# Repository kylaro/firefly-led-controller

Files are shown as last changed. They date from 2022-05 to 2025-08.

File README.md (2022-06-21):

# firefly-led-controller
PCB for the FireFly LED Controller by kylarLEDs

## Hardware
    The sensors on the board are:
        1. Microphone  -> for sound reactive LEDs
        2. Potentiometer  -> for brightness control
        3. Rotary encoder  -> for color/hue control
        4. Rotary encoder button  -> for changing patterns

    The outputs from the board are:
        1. 2 x WS2812B LED output pins 
            a. Each pin has 2 output pads, one on front and one on back
            b. Each pin has a 0.1 inch header port
        2. 2 x USBC 5V power up to 3A

    The input to the boards are:
        1. Pico programming micro usb port (not meant for power)
        2. 1 x USBC 5V power up to 3A

## Notes
Necessary improvements:
  * Support for 4 pin ws2812b strips, and APA102, 4 outputs
  * More testing capability for the microphone, and maybe other components
*     -> maybe bottom of board row of headers that another board with a pi can plug into, or row of pads on bottom
*     -> Or pad groups on the bottom, like this to that type things... every connection could be represented
*     -> ex. MIC GND <-> GND ... ENC_A <-> GP22 ..., anything that contributes functionality :) 
  * 4 LED outputs
  * Header pins offset

Possibile Improvements to make:
    *WIRELESS:
    *Add ESP32 S2 ($2) with PCB antenna, may need a 3.3V regulator unless the 3.3V port can handle it
  * Add a power MOSFET to turn on / off the power to LEDs
  * Have power pads for screw down crimped ring terminals?
  * Have a hole on the board to weave the LED wire through to add mechanical stability to solder connections
  * Support for 12V on board? (5v regulator, 5v dataline, but 12v power)
  * Support for automatically detecting strip length based on current drawn by strip (either "off" current or turning 1 on at a time, need ammeter)
  * Support for battery charging
  * Support for DMX LEDs input/output
  * Add more sensors, like motion sensor for human presence detection. Temperature/accelerometer/humidity/gyro...
  * Add silabs MCU for mesh networking
  * Stop using Pico board, use the RP2040 + pico schematic so we aren't soldering a board onto a board!

Notes:
  * USB C holes should be more exact so it fits better

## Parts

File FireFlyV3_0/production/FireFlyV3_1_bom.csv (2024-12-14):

Designator | Footprint | Quantity | Value | LCSC Part #
AE1 | FILTER-SMD_1206-2P-L3.2-W1.6-L | 1 | RFANT3216120A5T | C127629
C1, C10, C12, C13, C14, C16, C20, C24, C26, C3, C4, C5, C9 | 0402 | 13 | 100n | C1525
C11, C8 | 0402 | 2 | 15pF | C1548
C15, C18, C19 | 0603 | 3 | 10uF | C19702
C2 | 0402 | 1 | 2.2u | C12530
C21, C22 | 0402 | 2 | 1.5pF | C1552
C23, C25 | 0402 | 2 | 10pF | C32949
C6, C7 | 0402 | 2 | 1u | C52923
D1 | 0603 | 1 | LED, Yellow | C72038
D2 | D_SMA | 1 | SS34 | C8678
D3 | 0603 | 1 | LED, RED | C2286
J1, J2 | PinHeader_1x23_P2.54mm_Vertical | 2 | Conn_01x23
L1 | 0402 | 1 | 2.7nH | C98058
L2 | 0402 | 1 | 6.8nH | C77110
MIC1 | LGA-6_L4.7-W3.8-P1.65_LMD4737T | 1 | LMD4737T263-OY1 | C5373239
R1, R11, R13, R5 | 0402 | 4 | 22R | C25092
R10 | 0402 | 1 | 470R | C25117
R15, R16, R2, R9 | 0402 | 4 | 10K | C25744
R17, R6 | 0402 | 2 | 220R | C25091
R3 | 0402 | 1 | 200R | C25087
R4, R7 | 0402 | 2 | 1K | C11702
R8 | 0402 | 1 | 0R | C17168
SW1, SW2, SW3, SW4 | SW_SPST_TL3342 | 4 | BTN | C318884
U2 | SOIC-8_5.275x5.275mm_P1.27mm | 1 | W25Q128JVS | C97521
U3 | QFN-56-1EP_7x7mm_P0.4mm_EP3.2x3.2mm | 1 | RP2040 | C2040
U4 | SOT-223-3_TabPin2 | 1 | AMS1117-3.3 | C6186
U5 | ESP32-C3FH4 | 1 | ESP32-C3FH4 | C2858491
USB1, USB2 | USB-C_SMD-TYPE-C-31-M-12 | 2 | USB-TYPE-C-018 | C2927038
Y1 | Crystal_SMD_3225-4Pin_3.2x2.5mm | 1 | 12MHz, X322512MSB4SI | C9002
Y2 | Crystal_SMD_2520-4Pin_2.5x2.0mm | 1 | 40MHz, X252040MMB4SI | C2885592

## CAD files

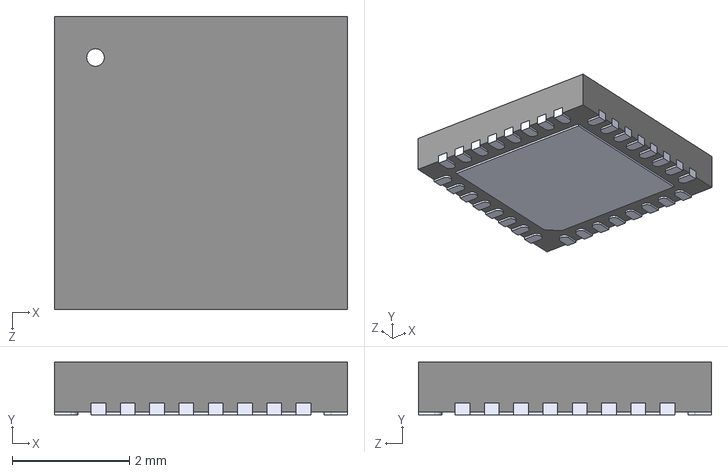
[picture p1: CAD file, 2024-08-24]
FireFlyV3_0/External_Components/models.3d/ESP32-C3FH4.step
5.00 x 0.9 x 5.00 mm

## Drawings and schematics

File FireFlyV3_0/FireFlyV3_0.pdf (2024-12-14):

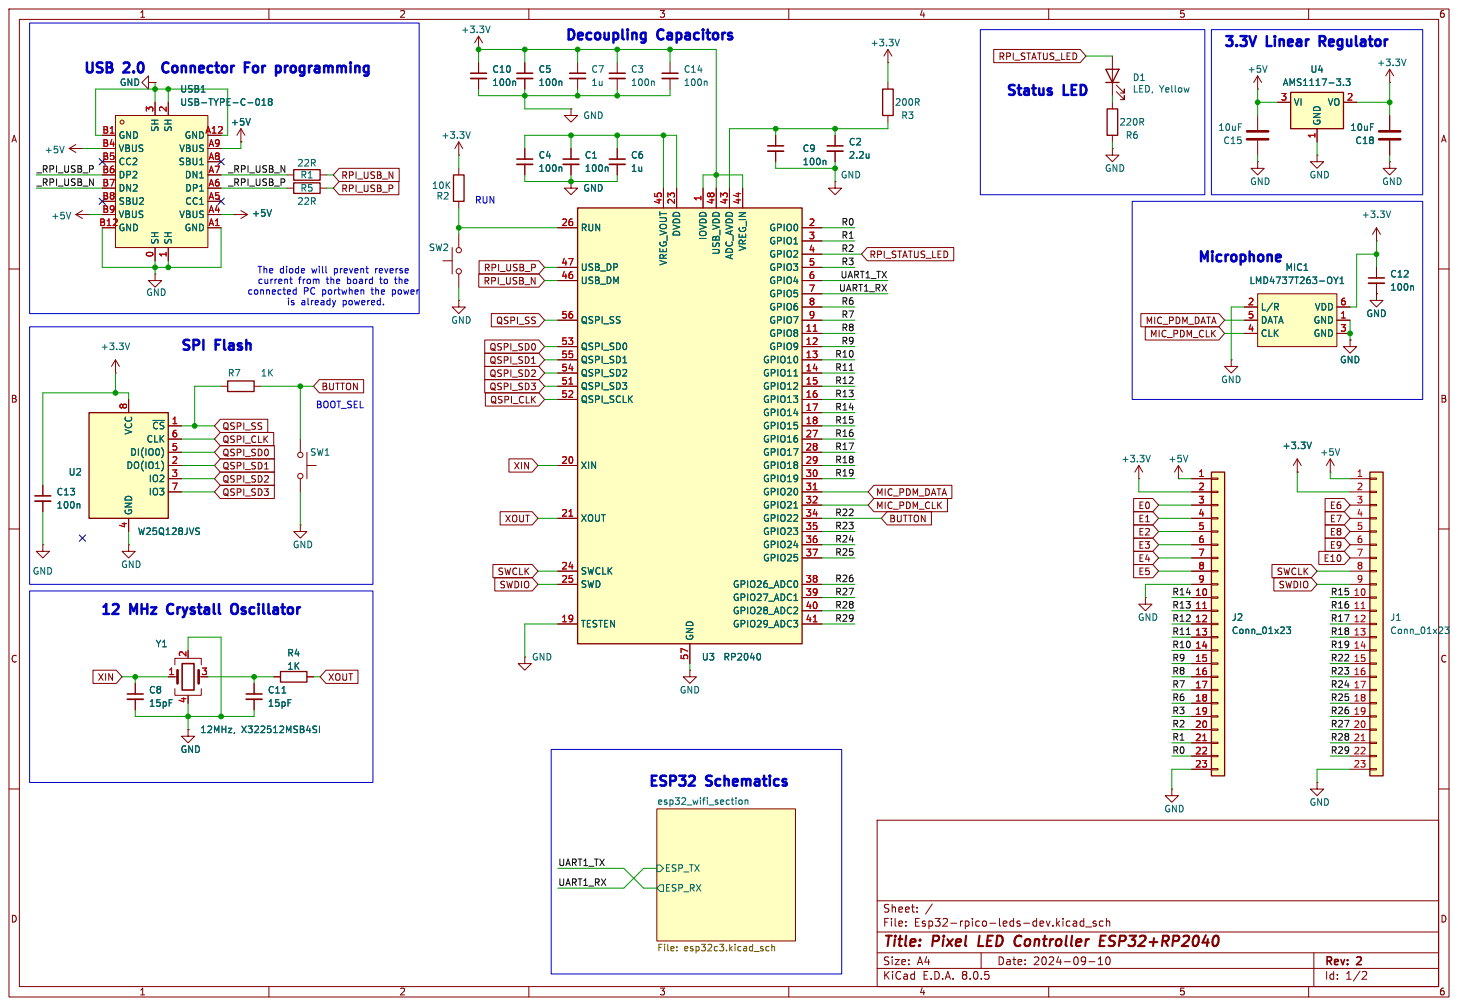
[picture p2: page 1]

3 GND A1 GNDA12 VBUS A4 CC1 A5 DP1 A6 DN1 A7 SBU1 A8 VBUS A9 GND B1 GND B12 VBUS B4 CC2 B5 DP2 B6 DN2 B7 SBU2 B8 VBUS B9 SH

1 GPIO8 11 GPIO9 12 GPIO10 13 GPIO11 14 GPIO12 15 GPIO13 16 GPIO14 17 GPIO15 18 TESTEN 19 GPIO0 2 XIN 20 XOUT 21 DVDD 23 SWCLK 24 SWD 25 RUN 26 GPIO16 27 GPIO17 28 GPIO18 29 GPIO1 3 GPIO19 30 GPIO20 31 GPIO21 32 GPIO22 34 GPIO23 35 GPIO24 36 GPIO25 37 GPIO26_ADC0 38 GPIO27_ADC1 39 GPIO2 4 GPIO28_ADC2 40 GPIO29_ADC3 41 ADC_AVDD 43 VREG_IN 44 VREG_VOUT 45 USB_DM 46 USB_DP 47 USB_VDD 48 GPIO3 5 QSPI_SD3 51 QSPI_SCLK 52 QSPI_SD0 53 QSPI_SD2 54 QSPI_SD1 55 QSPI_SS 56 GND 57 GPIO4 6 GPIO5 7 GPIO6 8 GPIO7 9 U3 RP2040 +5V R3
U3 RP2040 IOVDD

1 GPIO8 11 GPIO9 12 GPIO10 13 GPIO11 14 GPIO12 15 GPIO13 16 GPIO14 17 GPIO15 18 TESTEN 19 GPIO0 2 XIN 20 XOUT 21 DVDD 23 SWCLK 24 SWD 25 RUN 26 GPIO16 27 GPIO17 28 GPIO18 29 GPIO1 3 GPIO19 30 GPIO20 31 GPIO21 32 GPIO22 34 GPIO23 35 GPIO24 36 GPIO25 37 GPIO26_ADC0 38 GPIO27_ADC1 39 GPIO2 4 GPIO28_ADC2 40 GPIO29_ADC3 41 ADC_AVDD 43 VREG_IN 44 VREG_VOUT 45 USB_DM 46 USB_DP 47 USB_VDD 48 GPIO3 5 QSPI_SD3 51 QSPI_SCLK 52 QSPI_SD0 53 QSPI_SD2 54 QSPI_SD1 55 QSPI_SS 56 GND 57 GPIO4 6 GPIO5 7 GPIO6 8 GPIO7 9 +5V

The diode will prevent reverse
current from the board to the

File: Esp32-rpico-leds-dev.kicad_sch Sheet: / ESP_TX
ESP_RX

Id: 1/2 Title: Pixel LED Controller ESP32+RP2040

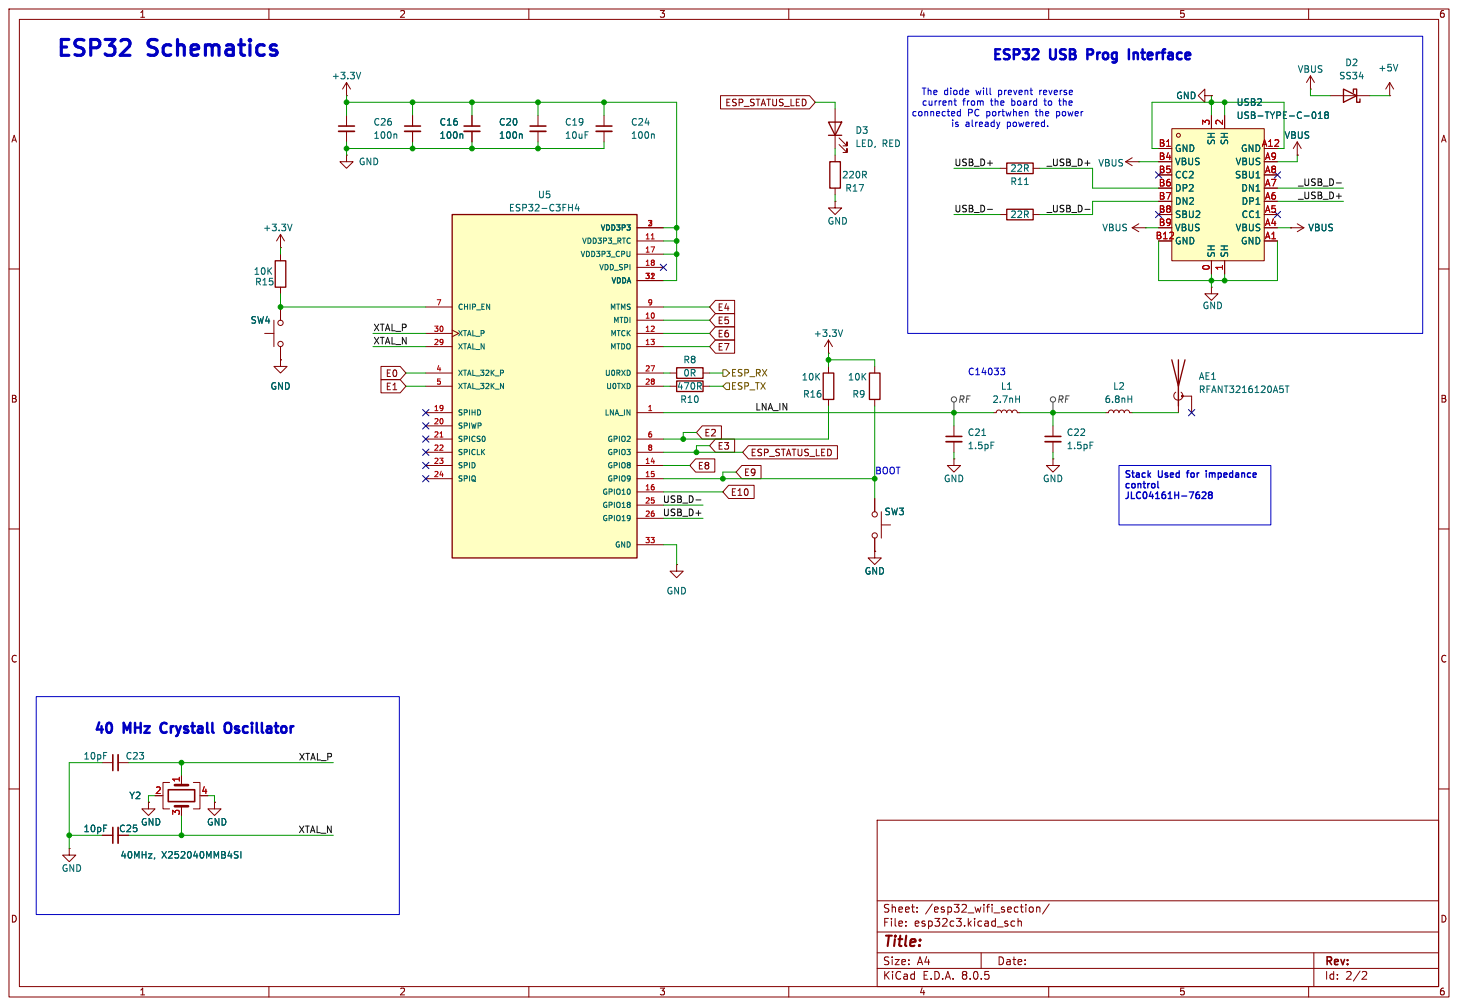
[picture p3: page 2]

The diode will prevent reverse
current from the board to the

1 USB2 USB-TYPE-C-018 VBUS RF RF ESP_TX
ESP_STATUS_LED

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

C14033 BOOT 40 MHz Crystall Oscillator
10K GND

Stack Used for impedance

Id: 2/2 Title: File: esp32c3.kicad_sch Sheet: /esp32_wifi_section/

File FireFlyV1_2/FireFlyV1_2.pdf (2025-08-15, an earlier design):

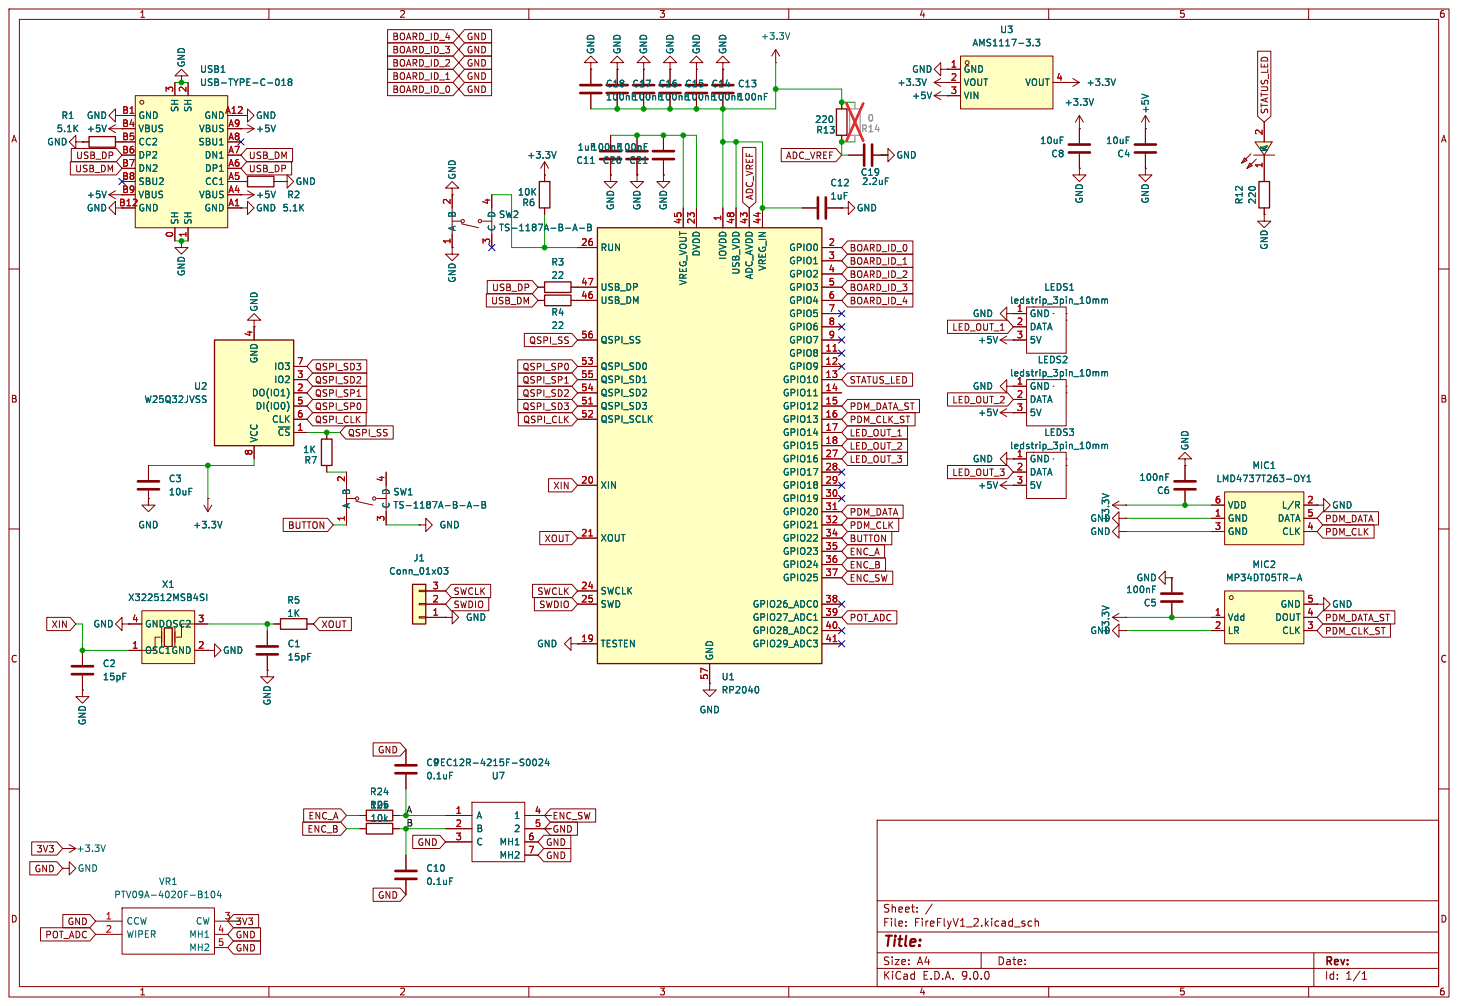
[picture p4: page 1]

1uF GND
+3.3V GND GND+3.3V GND GND

2 GNDA12 VBUS A9 SBU1 A8 DN1 A7 DP1 A6 CC1 A5 VBUS A4 GND A1 SH

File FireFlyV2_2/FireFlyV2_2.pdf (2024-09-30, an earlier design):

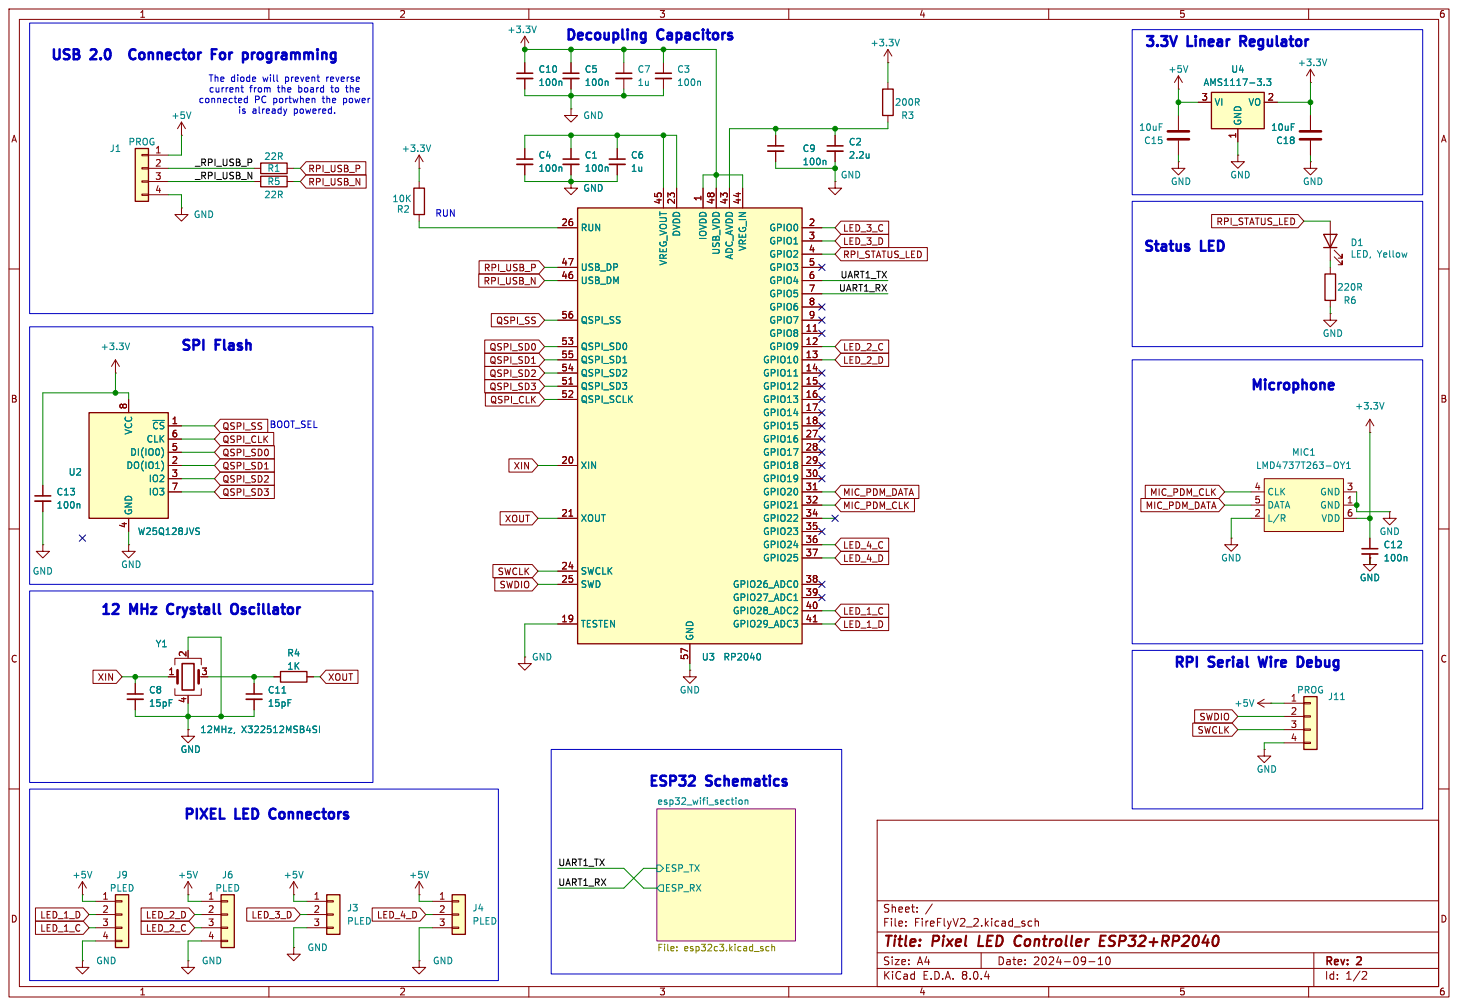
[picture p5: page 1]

+3.3V GND
The diode will prevent reverse
current from the board to the

1 GPIO8 11 GPIO9 12 GPIO10 13 GPIO11 14 GPIO12 15 GPIO13 16 GPIO14 17 GPIO15 18 TESTEN 19 GPIO0 2 XIN 20 XOUT 21 DVDD 23 SWCLK 24 SWD 25 RUN 26 GPIO16 27 GPIO17 28 GPIO18 29 GPIO1 3 GPIO19 30 GPIO20 31 GPIO21 32 GPIO22 34 GPIO23 35 GPIO24 36 GPIO25 37 GPIO26_ADC0 38 GPIO27_ADC1 39 GPIO2 4 GPIO28_ADC2 40 GPIO29_ADC3 41 ADC_AVDD 43 VREG_IN 44 VREG_VOUT 45 USB_DM 46 USB_DP 47 USB_VDD 48 GPIO3 5 QSPI_SD3 51 QSPI_SCLK 52 QSPI_SD0 53 QSPI_SD2 54 QSPI_SD1 55 QSPI_SS 56 GND 57 GPIO4 6 GPIO5 7 GPIO6 8 GPIO7 9 U3 RP2040

1 GPIO8 11 GPIO9 12 GPIO10 13 GPIO11 14 GPIO12 15 GPIO13 16 GPIO14 17 GPIO15 18 TESTEN 19 GPIO0 2 XIN 20 XOUT 21 DVDD 23 SWCLK 24 SWD 25 RUN 26 GPIO16 27 GPIO17 28 GPIO18 29 GPIO1 3 GPIO19 30 GPIO20 31 GPIO21 32 GPIO22 34 GPIO23 35 GPIO24 36 GPIO25 37 GPIO26_ADC0 38 GPIO27_ADC1 39 GPIO2 4 GPIO28_ADC2 40 GPIO29_ADC3 41 ADC_AVDD 43 VREG_IN 44 VREG_VOUT 45 USB_DM 46 USB_DP 47 USB_VDD 48 GPIO3 5 QSPI_SD3 51 QSPI_SCLK 52 QSPI_SD0 53 QSPI_SD2 54 QSPI_SD1 55 QSPI_SS 56 GND 57 GPIO4 6 GPIO5 7 GPIO6 8 GPIO7 9 GND

RPI Serial Wire Debug

Id: 1/2 Title: Pixel LED Controller ESP32+RP2040

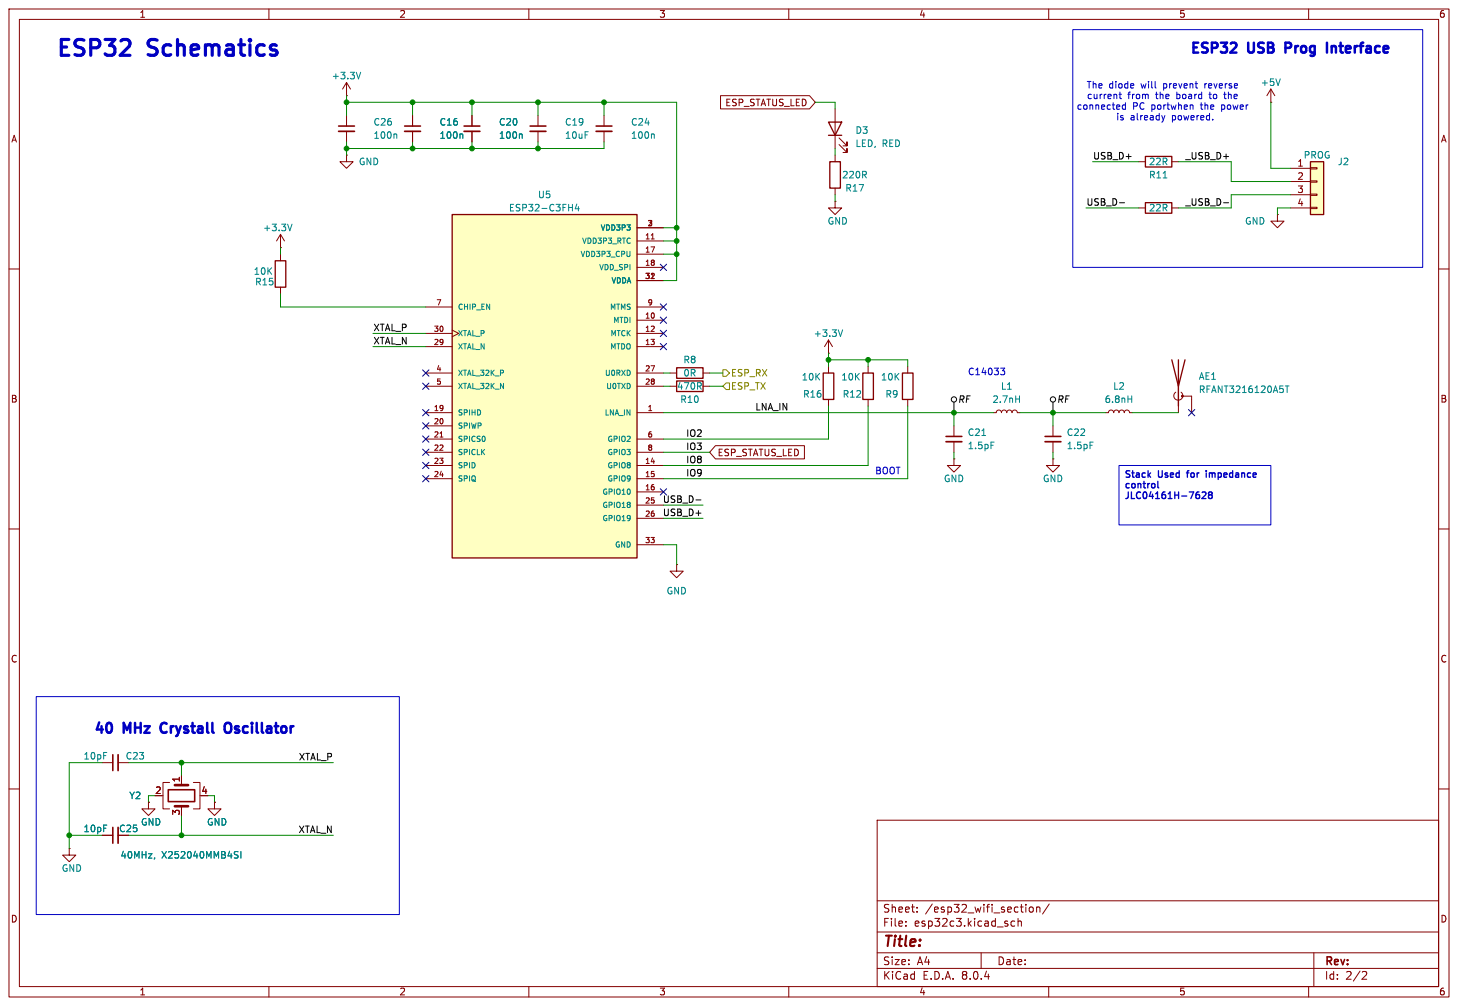
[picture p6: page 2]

current from the board to the

Id: 2/2 Title: File: esp32c3.kicad_sch Sheet: /esp32_wifi_section/

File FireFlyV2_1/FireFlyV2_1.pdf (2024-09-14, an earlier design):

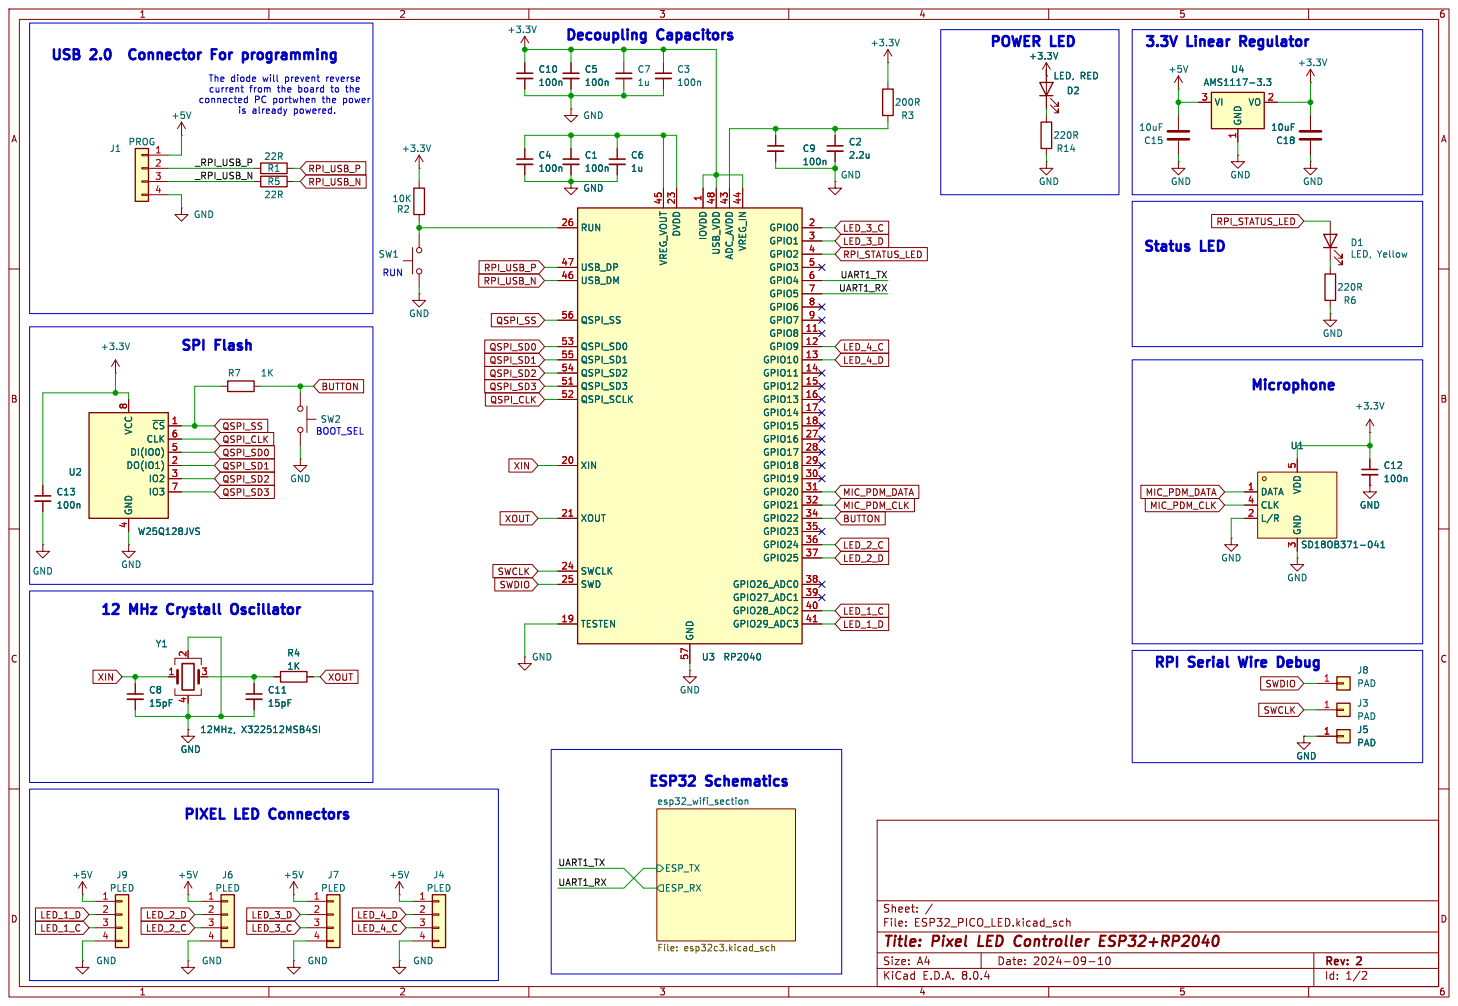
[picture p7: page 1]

The diode will prevent reverse
current from the board to the

1 GPIO8 11 GPIO9 12 GPIO10 13 GPIO11 14 GPIO12 15 GPIO13 16 GPIO14 17 GPIO15 18 TESTEN 19 GPIO0 2 XIN 20 XOUT 21 DVDD 23 SWCLK 24 SWD 25 RUN 26 GPIO16 27 GPIO17 28 GPIO18 29 GPIO1 3 GPIO19 30 GPIO20 31 GPIO21 32 GPIO22 34 GPIO23 35 GPIO24 36 GPIO25 37 GPIO26_ADC0 38 GPIO27_ADC1 39 GPIO2 4 GPIO28_ADC2 40 GPIO29_ADC3 41 ADC_AVDD 43 VREG_IN 44 VREG_VOUT 45 USB_DM 46 USB_DP 47 USB_VDD 48 GPIO3 5 QSPI_SD3 51 QSPI_SCLK 52 QSPI_SD0 53 QSPI_SD2 54 QSPI_SD1 55 QSPI_SS 56 GND 57 GPIO4 6 GPIO5 7 GPIO6 8 GPIO7 9 C4

1 GPIO8 11 GPIO9 12 GPIO10 13 GPIO11 14 GPIO12 15 GPIO13 16 GPIO14 17 GPIO15 18 TESTEN 19 GPIO0 2 XIN 20 XOUT 21 DVDD 23 SWCLK 24 SWD 25 RUN 26 GPIO16 27 GPIO17 28 GPIO18 29 GPIO1 3 GPIO19 30 GPIO20 31 GPIO21 32 GPIO22 34 GPIO23 35 GPIO24 36 GPIO25 37 GPIO26_ADC0 38 GPIO27_ADC1 39 GPIO2 4 GPIO28_ADC2 40 GPIO29_ADC3 41 ADC_AVDD 43 VREG_IN 44 VREG_VOUT 45 USB_DM 46 USB_DP 47 USB_VDD 48 GPIO3 5 QSPI_SD3 51 QSPI_SCLK 52 QSPI_SD0 53 QSPI_SD2 54 QSPI_SD1 55 QSPI_SS 56 GND 57 GPIO4 6 GPIO5 7 GPIO6 8 GPIO7 9 U3 RP2040

RPI Serial Wire Debug

Id: 1/2 Title: Pixel LED Controller ESP32+RP2040

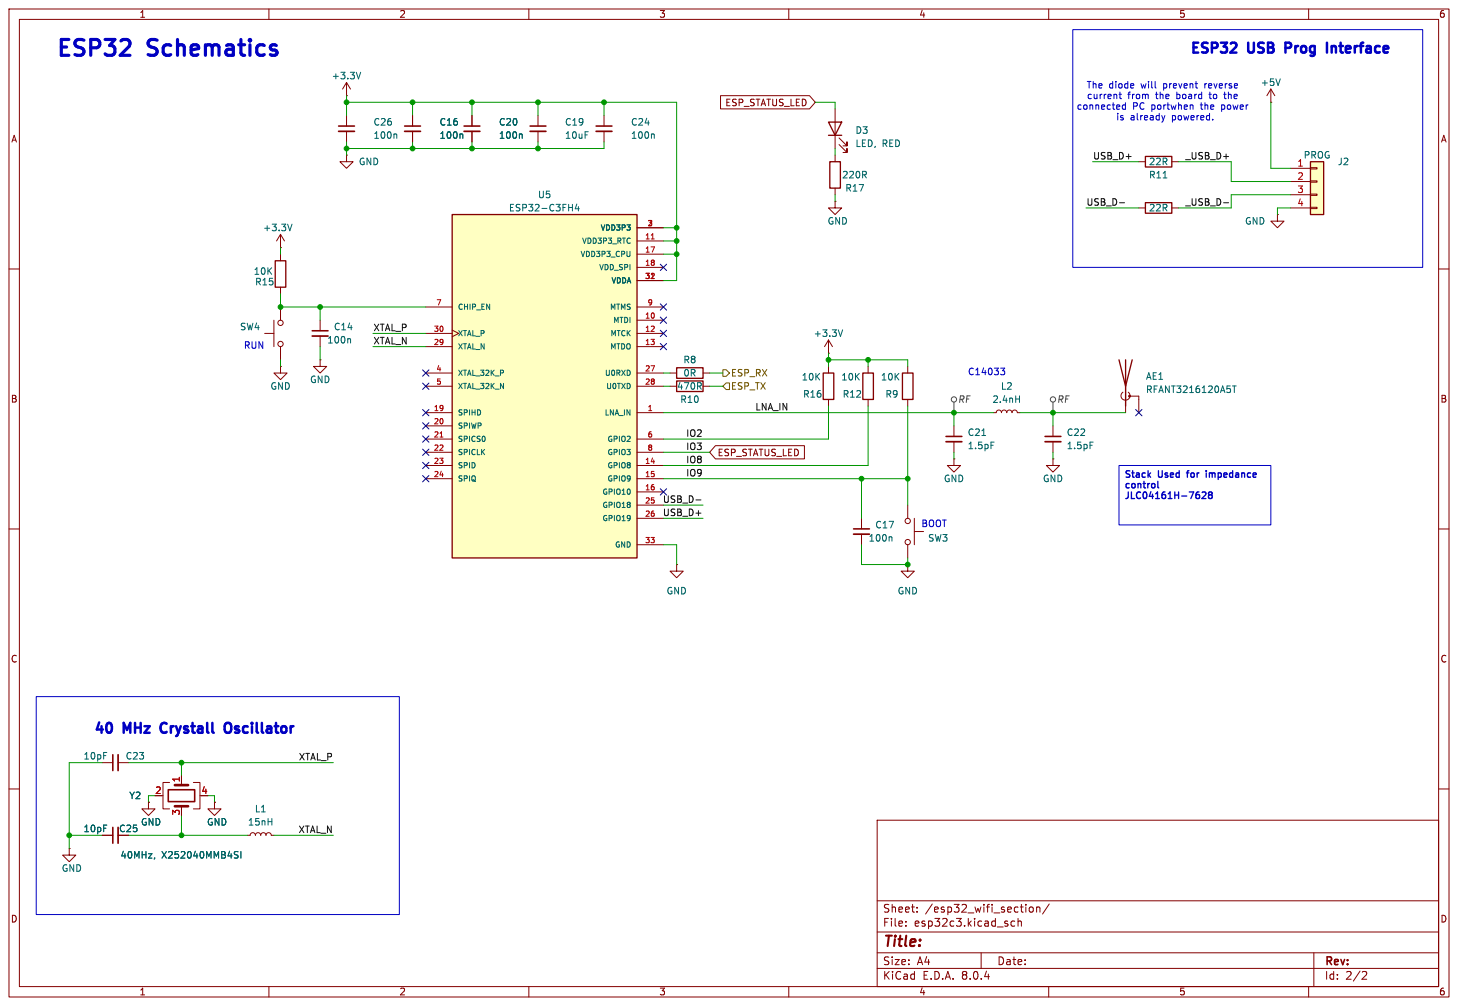
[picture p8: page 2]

The diode will prevent reverse
current from the board to the

Id: 2/2 Title: File: esp32c3.kicad_sch Sheet: /esp32_wifi_section/ GND

Stack Used for impedance

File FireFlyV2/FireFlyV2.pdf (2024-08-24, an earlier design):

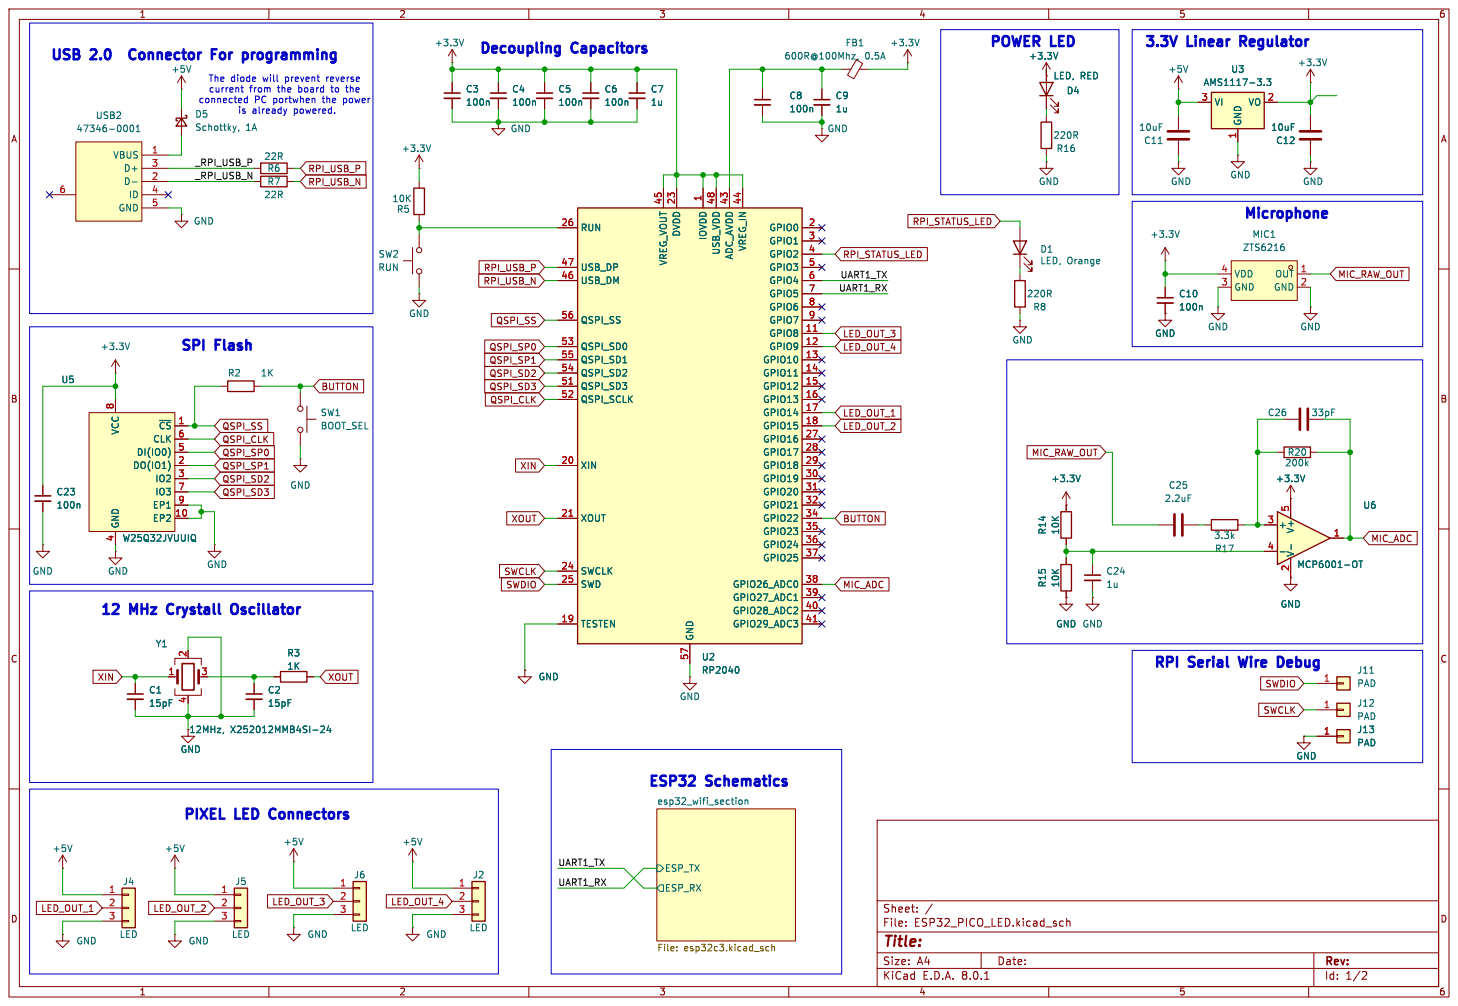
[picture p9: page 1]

1 GPIO8 11 GPIO9 12 GPIO10 13 GPIO11 14 GPIO12 15 GPIO13 16 GPIO14 17 GPIO15 18 TESTEN 19 GPIO0 2 XIN 20 XOUT 21 DVDD 23 SWCLK 24 SWD 25 RUN 26 GPIO16 27 GPIO17 28 GPIO18 29 GPIO1 3 GPIO19 30 GPIO20 31 GPIO21 32 GPIO22 34 GPIO23 35 GPIO24 36 GPIO25 37 GPIO26_ADC0 38 GPIO27_ADC1 39 GPIO2 4 GPIO28_ADC2 40 GPIO29_ADC3 41 ADC_AVDD 43 VREG_IN 44 VREG_VOUT 45 USB_DM 46 USB_DP 47 USB_VDD 48 GPIO3 5 QSPI_SD3 51 QSPI_SCLK 52 QSPI_SD0 53 QSPI_SD2 54 QSPI_SD1 55 QSPI_SS 56 GND 57 GPIO4 6 GPIO5 7 GPIO6 8 GPIO7 9 U3 AMS1117-3.3 GND

The diode will prevent reverse
current from the board to the

1 GPIO8 11 GPIO9 12 GPIO10 13 GPIO11 14 GPIO12 15 GPIO13 16 GPIO14 17 GPIO15 18 TESTEN 19 GPIO0 2 XIN 20 XOUT 21 DVDD 23 SWCLK 24 SWD 25 RUN 26 GPIO16 27 GPIO17 28 GPIO18 29 GPIO1 3 GPIO19 30 GPIO20 31 GPIO21 32 GPIO22 34 GPIO23 35 GPIO24 36 GPIO25 37 GPIO26_ADC0 38 GPIO27_ADC1 39 GPIO2 4 GPIO28_ADC2 40 GPIO29_ADC3 41 ADC_AVDD 43 VREG_IN 44 VREG_VOUT 45 USB_DM 46 USB_DP 47 USB_VDD 48 GPIO3 5 QSPI_SD3 51 QSPI_SCLK 52 QSPI_SD0 53 QSPI_SD2 54 QSPI_SD1 55 QSPI_SS 56 GND 57 GPIO4 6 GPIO5 7 GPIO6 8 GPIO7 9 U2 RP2040 +3.3V C23

RPI Serial Wire Debug

Id: 1/2 Title: File: ESP32_PICO_LED.kicad_sch Sheet: / ESP_TX
ESP_RX

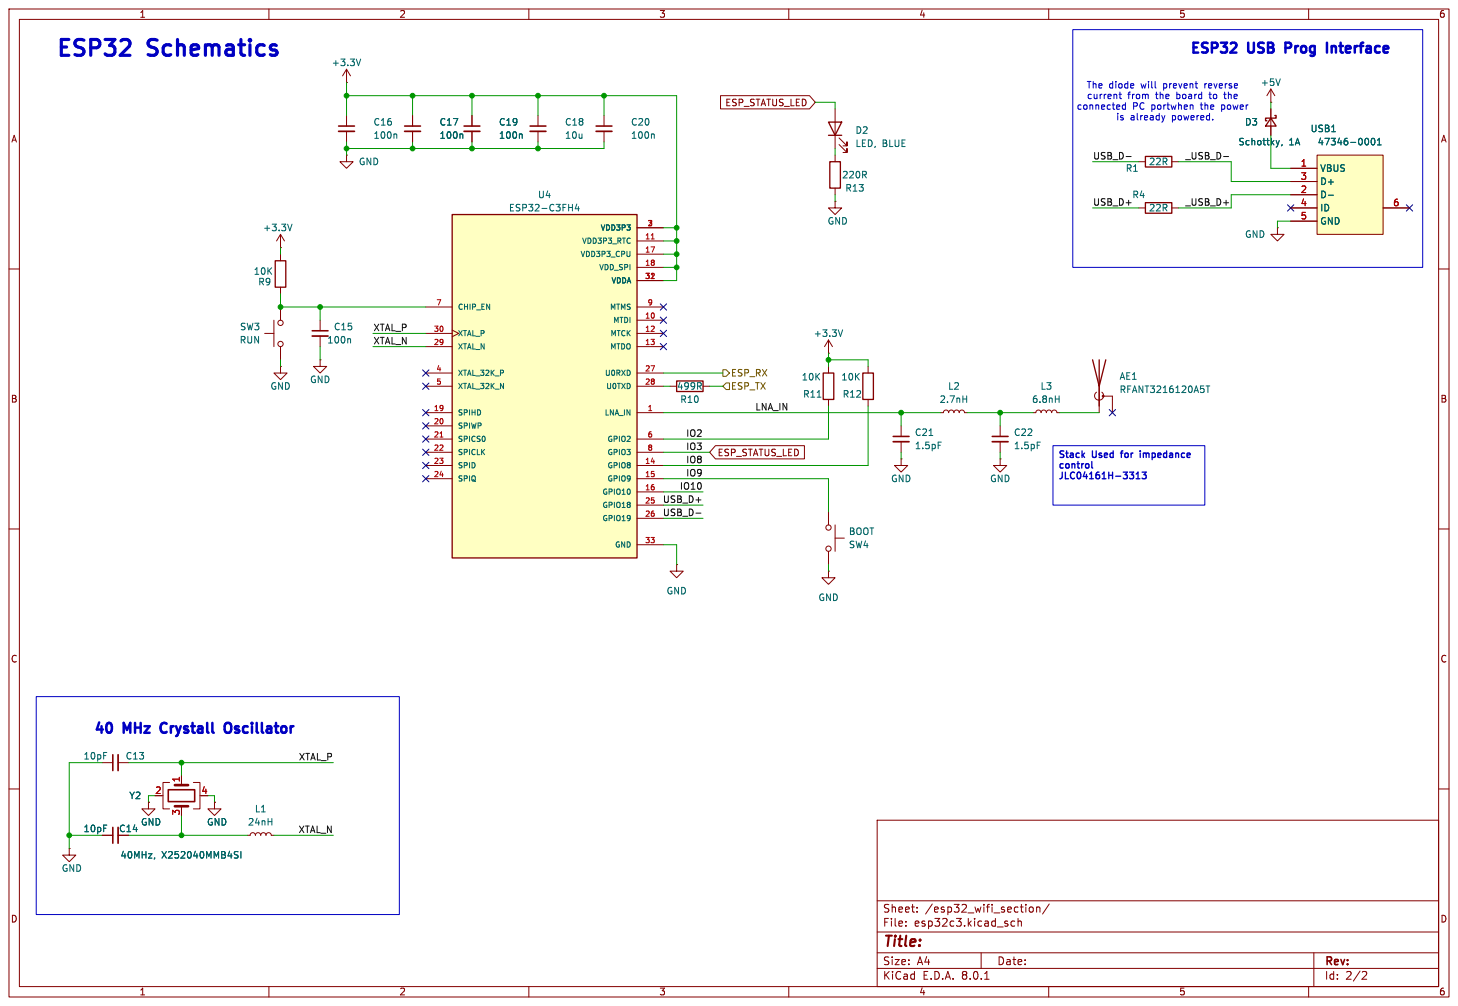
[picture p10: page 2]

The diode will prevent reverse
current from the board to the

Stack Used for impedance

Id: 2/2 Title: File: esp32c3.kicad_sch Sheet: /esp32_wifi_section/ GND

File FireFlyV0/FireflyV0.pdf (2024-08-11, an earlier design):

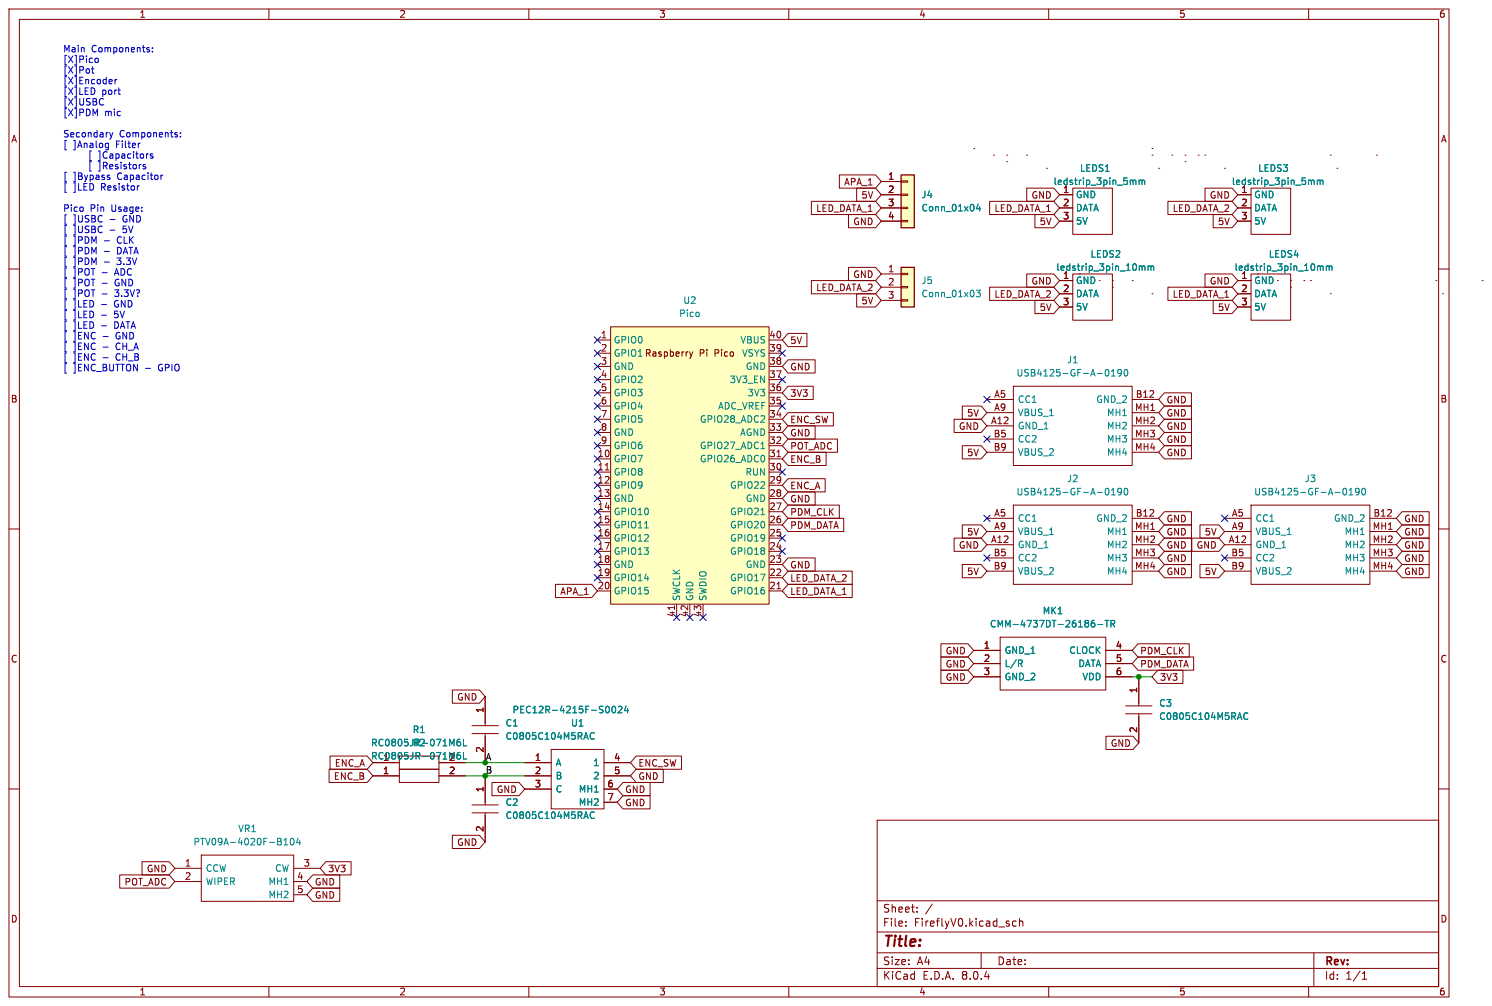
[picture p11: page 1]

[ ]Analog Filter
[ ]Bypass Capacitor
[ ]LED Resistor Pico Pin Usage:

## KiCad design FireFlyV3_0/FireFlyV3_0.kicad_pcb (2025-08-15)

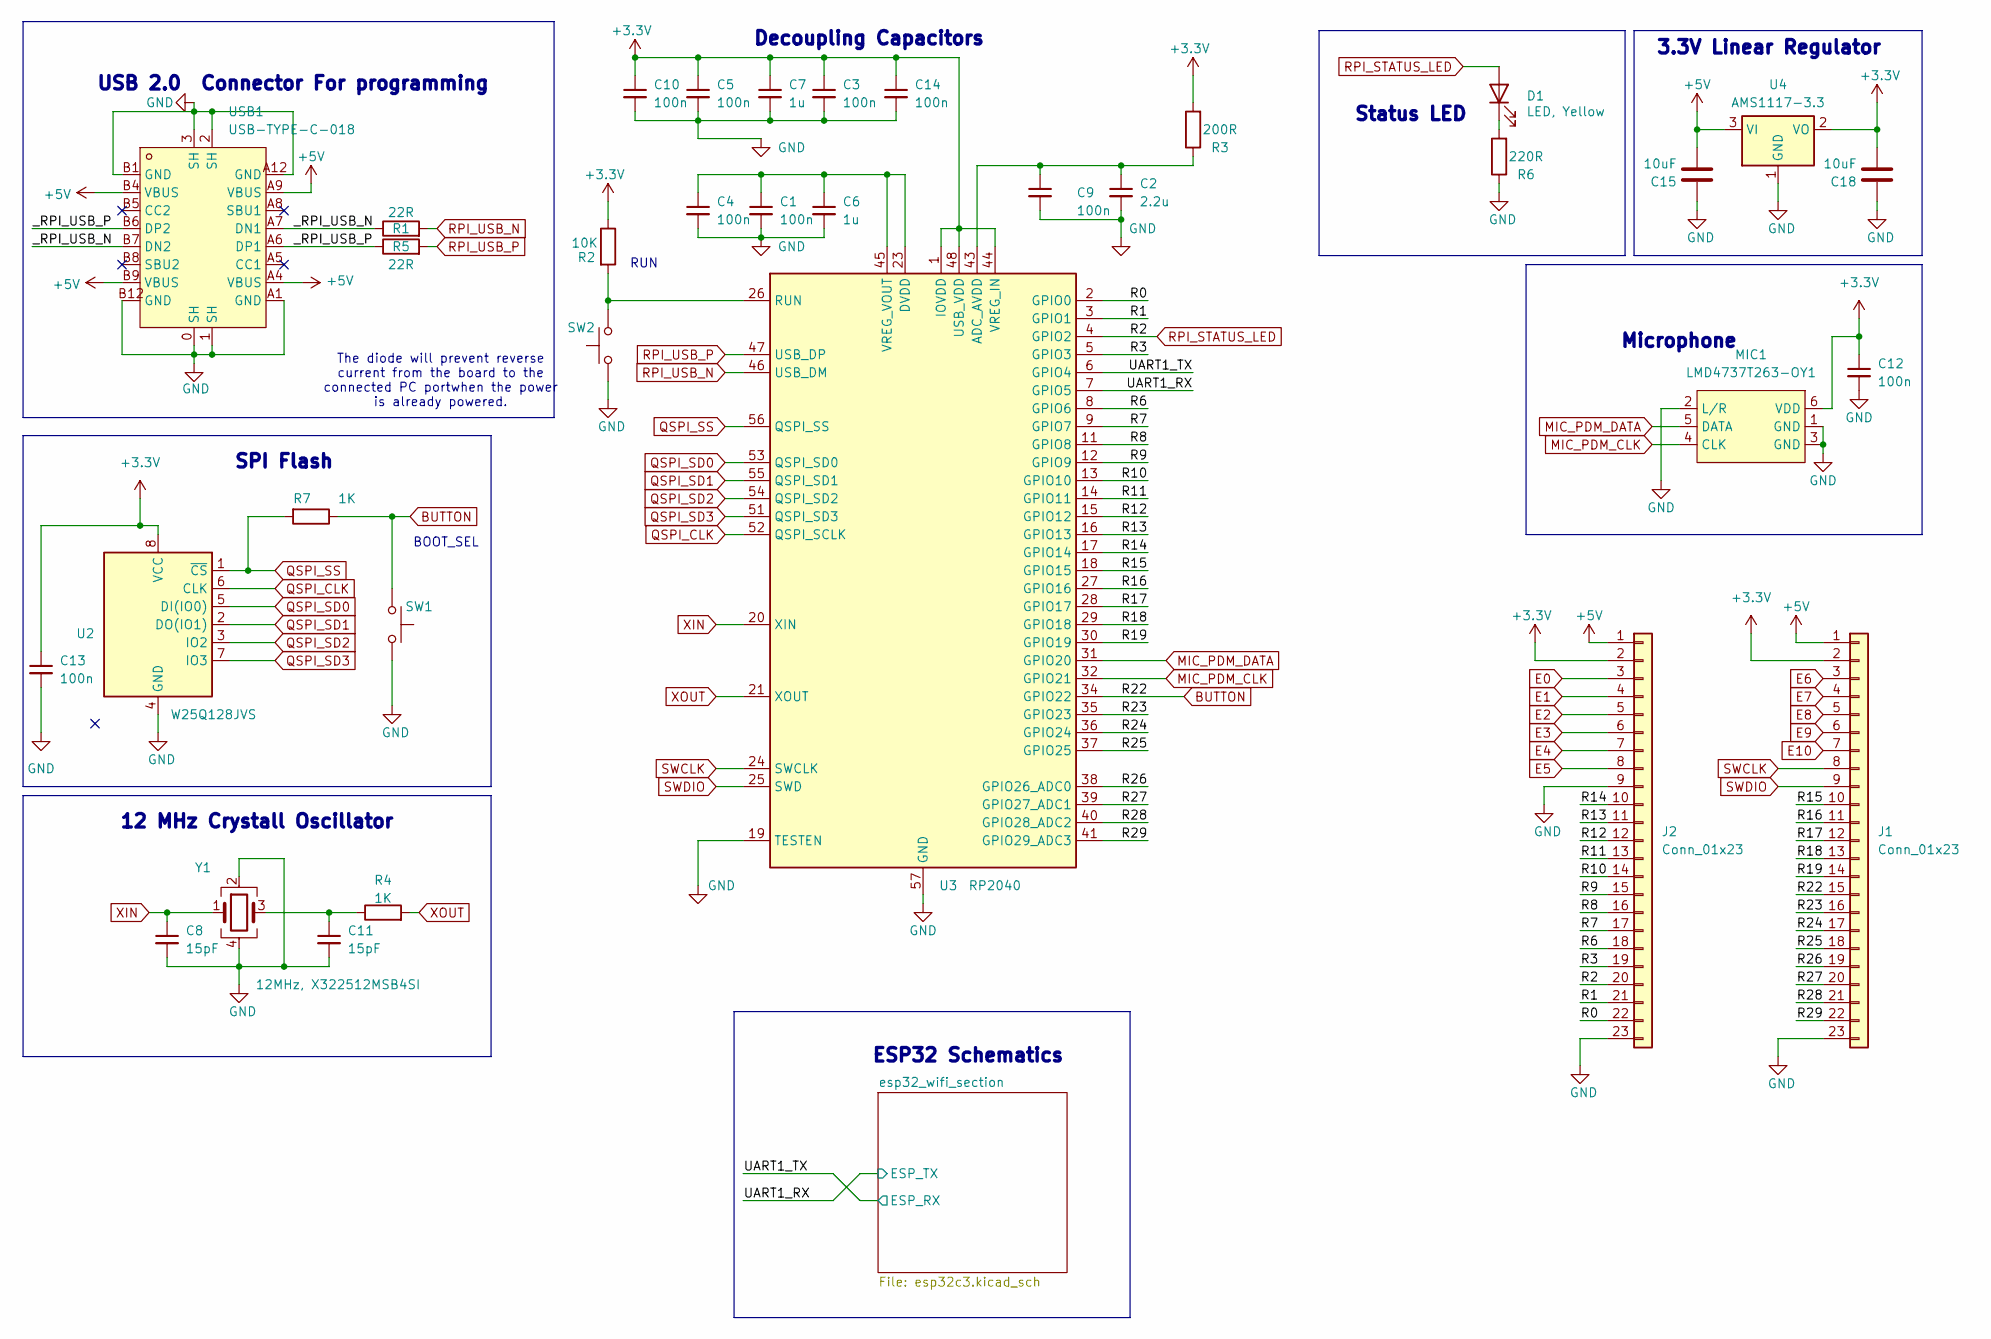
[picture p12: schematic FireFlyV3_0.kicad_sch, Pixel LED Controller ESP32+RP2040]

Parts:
C1, C3, C4, C5, C9, C10, C12, C13, C14: 100n; C_0402_1005Metric; LCSC Part C1525
C2: 2.2u; C_0402_1005Metric; LCSC Part C12530
C6, C7: 1u; C_0402_1005Metric; LCSC Part C52923
C8, C11: 15pF; C_0402_1005Metric; LCSC Part C1548
C15, C18: 10uF; C_0603_1608Metric; LCSC Part C19702
D1: LED, Yellow; LED_0603_1608Metric; LCSC Part C72038
J1, J2: Conn_01x23; PinHeader_1x23_P2.54mm_Vertical
MIC1: LMD4737T263-OY1; LGA-6_L4.7-W3.8-P1.65_LMD4737T; LCSC Part C5373239
R1, R5: 22R; R_0402_1005Metric; LCSC Part C25092
R2: 10K; R_0402_1005Metric; LCSC Part C25744
R3: 200R; R_0402_1005Metric; LCSC Part C25087
R4, R7: 1K; R_0402_1005Metric; LCSC Part C11702
R6: 220R; R_0402_1005Metric; LCSC Part C25091
SW1, SW2: BTN; SW_SPST_TL3342; LCSC Part C318884
U2: W25Q128JVS; SOIC-8_5.275x5.275mm_P1.27mm; LCSC Part C97521
U3: RP2040; QFN-56-1EP_7x7mm_P0.4mm_EP3.2x3.2mm; LCSC Part C2040
U4: AMS1117-3.3; SOT-223-3_TabPin2; LCSC Part C6186
USB1: USB-TYPE-C-018; USB-C_SMD-TYPE-C-31-M-12; LCSC Part C2927038
Y1: 12MHz, X322512MSB4SI; Crystal_SMD_3225-4Pin_3.2x2.5mm; LCSC Part C9002

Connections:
+3.3V: C3.1, C5.1, C7.1, C10.1, C12.1, C13.1, C14.1, C18.1, J1.2, J2.2, MIC1.6 (VDD), R2.1, R3.2, U2.8 (VCC), U3.1 (IOVDD), U3.10 (IOVDD), U3.22 (IOVDD), U3.33 (IOVDD), U3.42 (IOVDD), U3.44 (VREG_IN), U3.48 (USB_VDD), U3.49 (IOVDD), U4.2 (VO); also elsewhere on the board
+5V: C15.1, J1.1, J2.1, U4.3 (VI), USB1.A4 (VBUS), USB1.A9 (VBUS), USB1.B4 (VBUS), USB1.B9 (VBUS); also elsewhere on the board
/R0: J2.22, U3.2 (GPIO0)
/R1: J2.21, U3.3 (GPIO1)
/R3: J2.19, U3.5 (GPIO3)
/R6: J2.18, U3.8 (GPIO6)
/R7: J2.17, U3.9 (GPIO7)
/R8: J2.16, U3.11 (GPIO8)
/R9: J2.15, U3.12 (GPIO9)
/R10: J2.14, U3.13 (GPIO10)
/R11: J2.13, U3.14 (GPIO11)
/R12: J2.12, U3.15 (GPIO12)
/R13: J2.11, U3.16 (GPIO13)
/R14: J2.10, U3.17 (GPIO14)
/R15: J1.10, U3.18 (GPIO15)
/R16: J1.11, U3.27 (GPIO16)
/R17: J1.12, U3.28 (GPIO17)
/R18: J1.13, U3.29 (GPIO18)
/R19: J1.14, U3.30 (GPIO19)
/R23: J1.16, U3.35 (GPIO23)
/R24: J1.17, U3.36 (GPIO24)
/R25: J1.18, U3.37 (GPIO25)
/R26: J1.19, U3.38 (GPIO26_ADC0)
/R27: J1.20, U3.39 (GPIO27_ADC1)
/R28: J1.21, U3.40 (GPIO28_ADC2)
/R29: J1.22, U3.41 (GPIO29_ADC3)
/UART1_RX: U3.7 (GPIO5); also elsewhere on the board
/UART1_TX: U3.6 (GPIO4); also elsewhere on the board
/_RPI_USB_N: R1.1, USB1.A7 (DN1), USB1.B7 (DN2)
/_RPI_USB_P: R5.1, USB1.A6 (DP1), USB1.B6 (DP2)
BUTTON: J1.15, R7.1, SW1.1, U3.34 (GPIO22)
E0: J2.3; also elsewhere on the board
E1: J2.4; also elsewhere on the board
E2: J2.5; also elsewhere on the board
E3: J2.6; also elsewhere on the board
E4: J2.7; also elsewhere on the board
E5: J2.8; also elsewhere on the board
E6: J1.3; also elsewhere on the board
E7: J1.4; also elsewhere on the board
E8: J1.5; also elsewhere on the board
E9: J1.6; also elsewhere on the board
E10: J1.7; also elsewhere on the board
GND: C1.2, C2.2, C3.2, C4.2, C5.2, C6.2, C7.2, C8.2, C9.2, C10.2, C11.2, C12.2, C13.2, C14.2, C15.2, C18.2, J1.23, J2.9, J2.23, MIC1.1 (GND), MIC1.2 (L/R), MIC1.3 (GND), R6.1, SW1.2, SW2.2, U2.4 (GND), U3.19 (TESTEN), U3.57 (GND), U4.1 (GND), USB1.0 (SH), USB1.1 (SH), USB1.2 (SH), USB1.3 (SH), USB1.A1 (GND), USB1.A12 (GND), USB1.B1 (GND), USB1.B12 (GND), Y1.2, Y1.4; also elsewhere on the board
MIC_PDM_CLK: MIC1.4 (CLK), U3.32 (GPIO21)
MIC_PDM_DATA: MIC1.5 (DATA), U3.31 (GPIO20)
unnamed: C11.1, R4.1, Y1.3
unnamed: D1.1 (K), R6.2
unnamed: C2.1, C9.1, R3.1, U3.43 (ADC_AVDD)
unnamed: R2.2, SW2.1, U3.26 (RUN)
unnamed: C1.1, C4.1, C6.1, U3.23 (DVDD), U3.45 (VREG_VOUT), U3.50 (DVDD)
QSPI_CLK: U2.6 (CLK), U3.52 (QSPI_SCLK)
QSPI_SD0: U2.5 (DI(IO0)), U3.53 (QSPI_SD0)
QSPI_SD1: U2.2 (DO(IO1)), U3.55 (QSPI_SD1)
QSPI_SD2: U2.3 (IO2), U3.54 (QSPI_SD2)
QSPI_SD3: U2.7 (IO3), U3.51 (QSPI_SD3)
QSPI_SS: R7.2, U2.1 (~CS), U3.56 (QSPI_SS)
RPI_STATUS_LED: D1.2 (A), J2.20, U3.4 (GPIO2)
RPI_USB_N: R1.2, U3.46 (USB_DM)
RPI_USB_P: R5.2, U3.47 (USB_DP)
SWCLK: J1.8, U3.24 (SWCLK)
SWDIO: J1.9, U3.25 (SWD)
XIN: C8.1, U3.20 (XIN), Y1.1
XOUT: R4.2, U3.21 (XOUT)

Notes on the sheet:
3.3V Linear Regulator
Microphone
SPI Flash
Decoupling Capacitors
12 MHz Crystall Oscillator
RUN
The diode will prevent reverse current from the board to the connected PC portwhen the power is already powered.
USB 2.0 Connector For programming
BOOT_SEL
Status LED
ESP32 Schematics

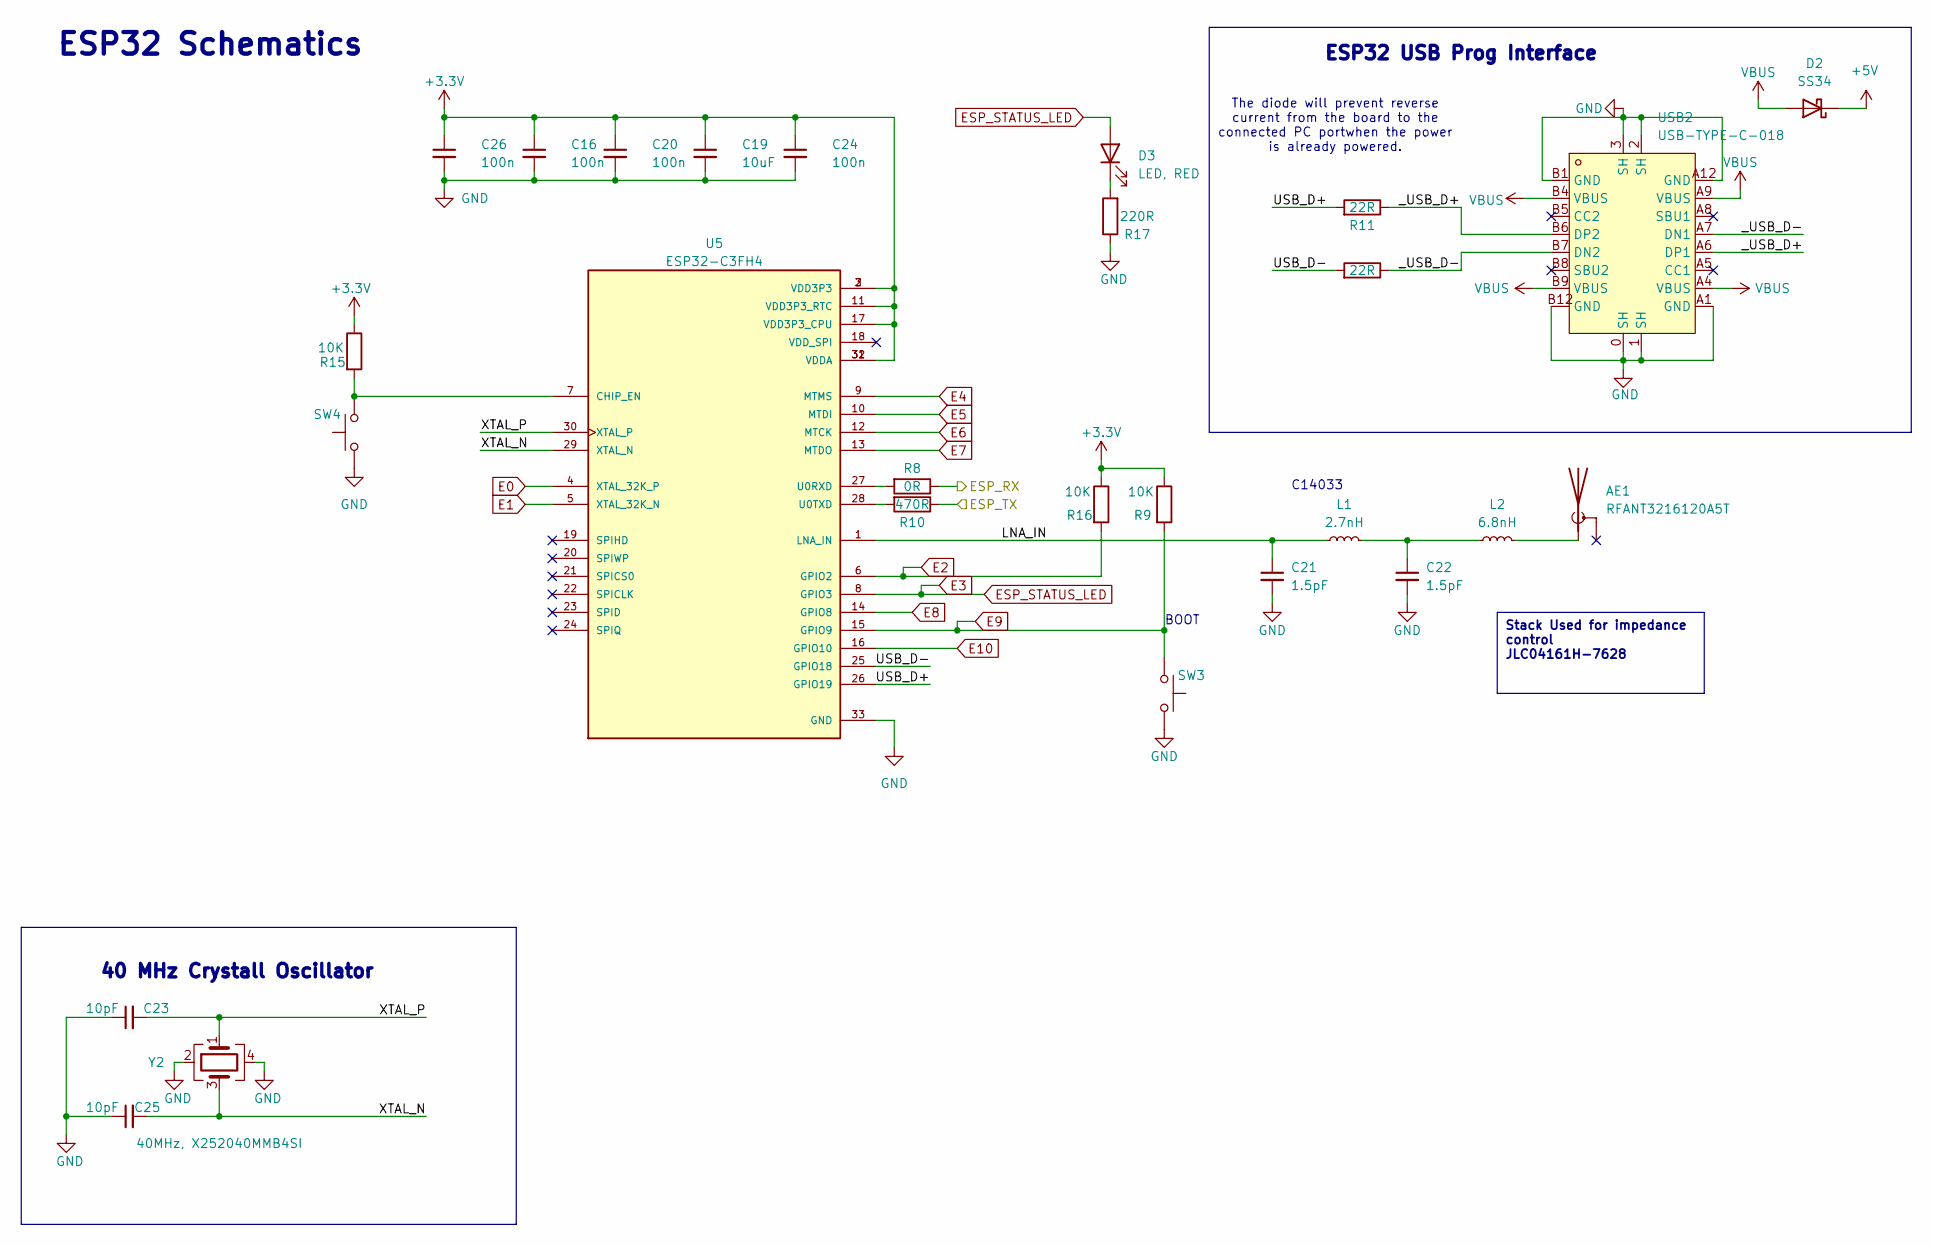
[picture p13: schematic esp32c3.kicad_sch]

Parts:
AE1: RFANT3216120A5T; FILTER-SMD_1206-2P-L3.2-W1.6-L; LCSC Part C127629
C16, C20, C24, C26: 100n; C_0402_1005Metric; LCSC Part C1525
C19: 10uF; C_0603_1608Metric; LCSC Part C19702
C21, C22: 1.5pF; C_0402_1005Metric; LCSC Part C1552
C23, C25: 10pF; C_0402_1005Metric; LCSC Part C32949
D2: SS34; D_SMA; LCSC Part C8678
D3: LED, RED; LED_0603_1608Metric; LCSC Part C2286
L1: 2.7nH; L_0402_1005Metric; LCSC Part C98058
L2: 6.8nH; L_0402_1005Metric; LCSC Part C77110
R8: 0R; R_0402_1005Metric; LCSC Part C17168
R9, R15, R16: 10K; R_0402_1005Metric; LCSC Part C25744
R10: 470R; R_0402_1005Metric; LCSC Part C25117
R11, R13: 22R; R_0402_1005Metric; LCSC Part C25092
R17: 220R; R_0402_1005Metric; LCSC Part C25091
SW3, SW4: BTN; SW_SPST_TL3342; LCSC Part C318884
U5: ESP32-C3FH4; MPN ESP32-C3FH4; LCSC Part C2858491
USB2: USB-TYPE-C-018; USB-C_SMD-TYPE-C-31-M-12; LCSC Part C2927038
Y2: 40MHz, X252040MMB4SI; Crystal_SMD_2520-4Pin_2.5x2.0mm; LCSC Part C2885592

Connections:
+3.3V: C16.1, C19.1, C20.1, C24.1, C26.1, R9.1, R15.1, R16.1, U5.2 (VDD3P3), U5.3 (VDD3P3), U5.11 (VDD3P3_RTC), U5.17 (VDD3P3_CPU), U5.31 (VDDA), U5.32 (VDDA); also elsewhere on the board
+5V: D2.1 (K); also elsewhere on the board
/UART1_RX: R10.1; also elsewhere on the board
/UART1_TX: R8.1; also elsewhere on the board
/esp32_wifi_section/LNA_IN: C21.1, L1.1, U5.1 (LNA_IN)
/esp32_wifi_section/USB_D+: R11.2, U5.26 (GPIO19)
/esp32_wifi_section/USB_D-: R13.2, U5.25 (GPIO18)
/esp32_wifi_section/XTAL_N: C25.2, U5.29 (XTAL_N), Y2.3
/esp32_wifi_section/XTAL_P: C23.2, U5.30 (XTAL_P), Y2.1
/esp32_wifi_section/_USB_D+: R11.1, USB2.A6 (DP1), USB2.B6 (DP2)
/esp32_wifi_section/_USB_D-: R13.1, USB2.A7 (DN1), USB2.B7 (DN2)
E0: U5.4 (XTAL_32K_P); also elsewhere on the board
E1: U5.5 (XTAL_32K_N); also elsewhere on the board
E2: R16.2, U5.6 (GPIO2); also elsewhere on the board
E3: D3.2 (A), U5.8 (GPIO3); also elsewhere on the board
E4: U5.9 (MTMS); also elsewhere on the board
E5: U5.10 (MTDI); also elsewhere on the board
E6: U5.12 (MTCK); also elsewhere on the board
E7: U5.13 (MTDO); also elsewhere on the board
E8: U5.14 (GPIO8); also elsewhere on the board
E9: R9.2, SW3.1, U5.15 (GPIO9); also elsewhere on the board
E10: U5.16 (GPIO10); also elsewhere on the board
GND: C16.2, C19.2, C20.2, C21.2, C22.2, C23.1, C24.2, C25.1, C26.2, R17.1, SW3.2, SW4.2, U5.33 (GND), USB2.0 (SH), USB2.1 (SH), USB2.2 (SH), USB2.3 (SH), USB2.A1 (GND), USB2.A12 (GND), USB2.B1 (GND), USB2.B12 (GND), Y2.2, Y2.4; also elsewhere on the board
unnamed: AE1.1 (A), L2.2
unnamed: C22.1, L1.2, L2.1
unnamed: D3.1 (K), R17.2
unnamed: R15.2, SW4.1, U5.7 (CHIP_EN)
unnamed: R8.2, U5.27 (U0RXD)
unnamed: R10.2, U5.28 (U0TXD)
VBUS: D2.2 (A), USB2.A4 (VBUS), USB2.A9 (VBUS), USB2.B4 (VBUS), USB2.B9 (VBUS)

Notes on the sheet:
Stack Used for impedance control JLC04161H-7628
40 MHz Crystall Oscillator
The diode will prevent reverse current from the board to the connected PC portwhen the power is already powered.
ESP32 Schematics
C14033
ESP32 USB Prog Interface
BOOT

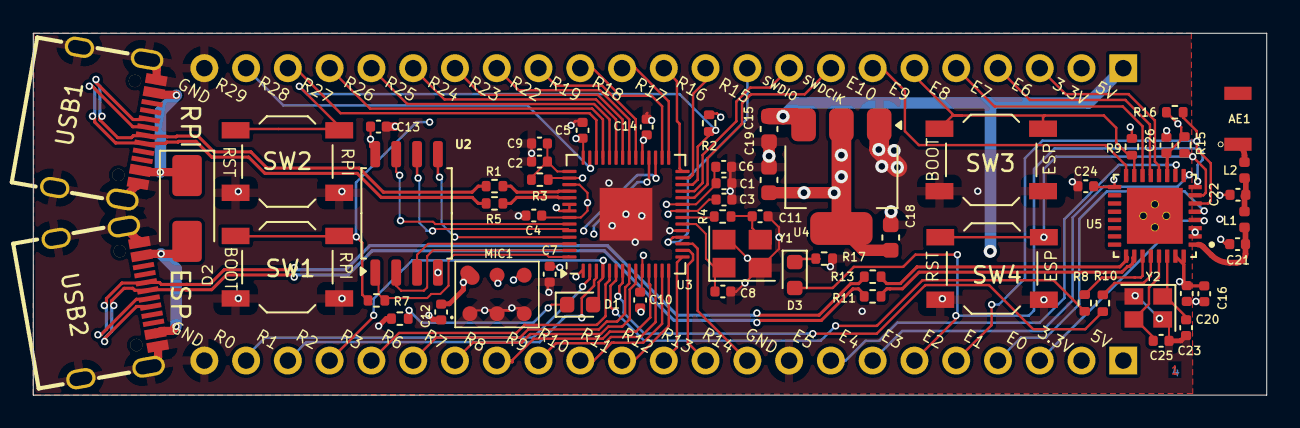
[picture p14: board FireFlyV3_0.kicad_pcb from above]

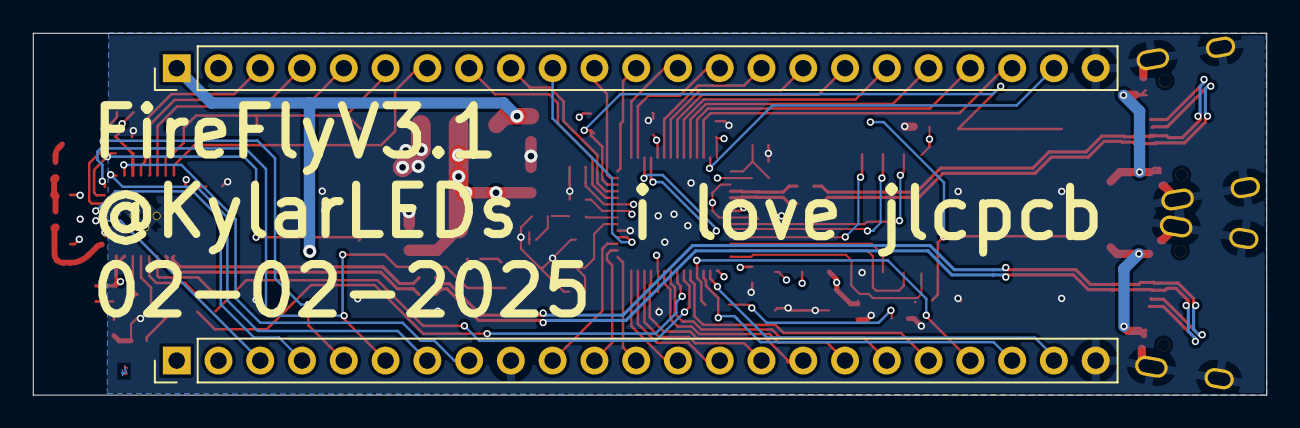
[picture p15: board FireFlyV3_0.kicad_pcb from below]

Board: 4 copper layers, 75.0 x 22.0 mm, 61 parts (2 on the bottom side), 77 nets.

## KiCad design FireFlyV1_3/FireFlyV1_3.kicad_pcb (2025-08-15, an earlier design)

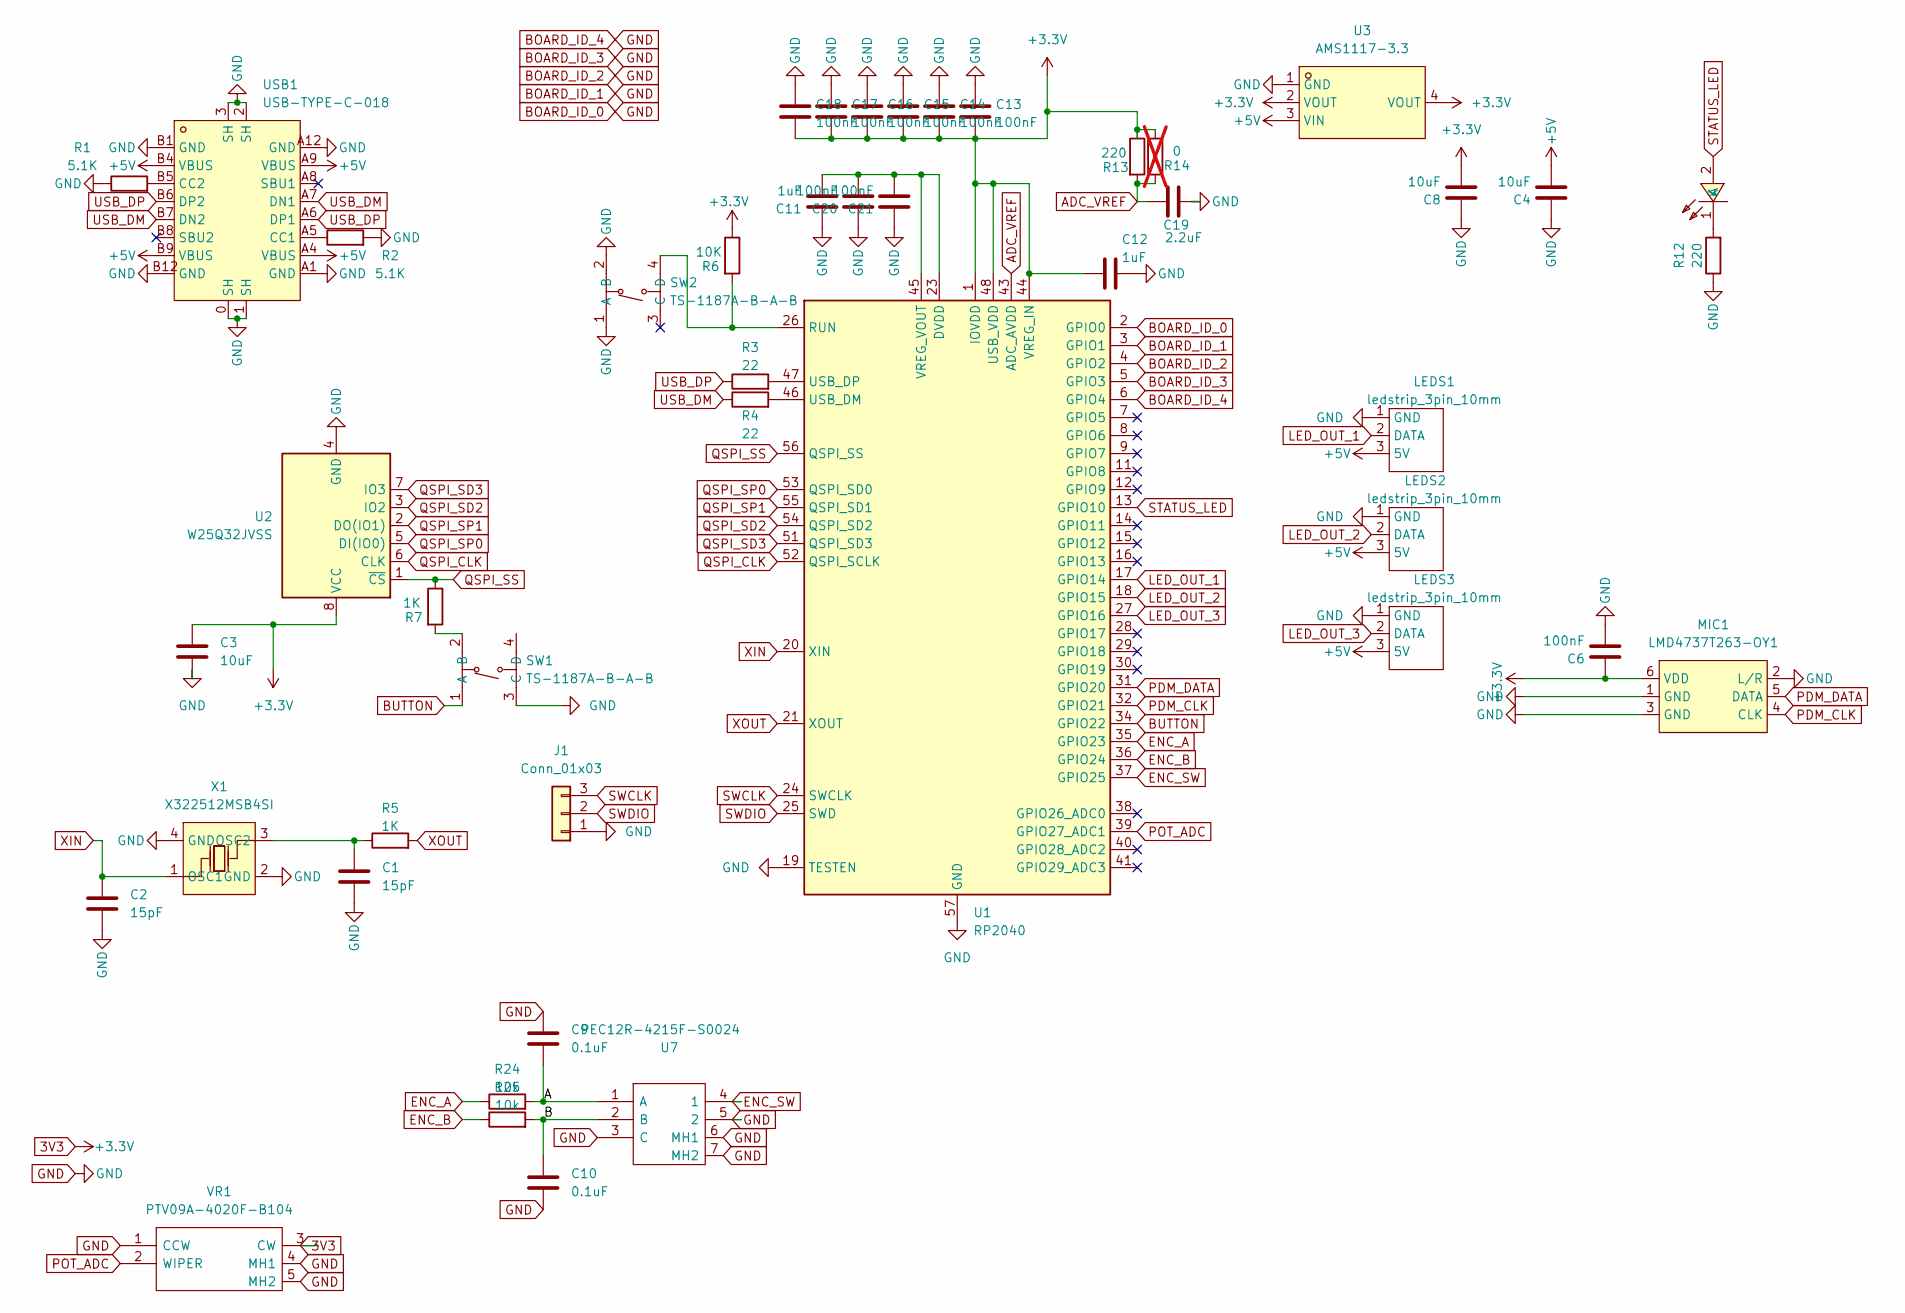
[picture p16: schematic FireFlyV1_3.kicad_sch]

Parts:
C1, C2: 15pF; C_0402_1005Metric
C3, C4, C8: 10uF; C_0402_1005Metric
C6, C13, C14, C15, C16, C17, C18, C20, C21: 100nF; C_0402_1005Metric
C9, C10: 0.1uF; C_0402_1005Metric
C11, C12: 1uF; C_0402_1005Metric
C19: 2.2uF; C_0402_1005Metric
J1: Conn_01x03; PinHeader_1x03_P2.54mm_Vertical
LED1: KT-0603R; LED0603-RD; LCSC Part C2286
LEDS1, LEDS2, LEDS3: ledstrip_3pin_10mm; ledstrip_3pin_withpins
MIC1: LMD4737T263-OY1; LGA-6_L4.7-W3.8-P1.65_LMD4737T; LCSC Part C5373239
R1, R2: 5.1K; R_0402_1005Metric
R3, R4: 22; R_0402_1005Metric
R5, R7: 1K; R_0402_1005Metric
R6: 10K; R_0402_1005Metric
R12, R13: 220; R_0402_1005Metric
R14: 0; R_0402_1005Metric; not fitted
R24, R25: 10k; R_0402_1005Metric
SW1, SW2: TS-1187A-B-A-B; SW-SMD_4P-L5.1-W5.1-P3.70-LS6.5-TL-2; LCSC Part C318884
U1: RP2040; QFN-56-1EP_7x7mm_P0.4mm_EP3.2x3.2mm
U2: W25Q32JVSS; SOIC-8_5.23x5.23mm_P1.27mm
U3: AMS1117-3.3; SOT-223-3_L6.5-W3.4-P2.30-LS7.0-BR; LCSC Part C6186
U7: PEC12R-4215F-S0024; PEC12R-4XXXF-SXXXX_court; Mouser Part Number 652-PEC12R-4215F-S24
USB1: USB-TYPE-C-018; USB-C_SMD-TYPE-C-31-M-12; LCSC Part C2927038
VR1: PTV09A-4020F-B104; PTV09A4020FB103; Mouser Part Number 652-PTV09A-4020FB104
X1: X322512MSB4SI; OSC-SMD_4P-L3.2-W2.5-BL; LCSC Part C9002

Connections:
3V3: C3.2, C6.2, C8.1, C12.1, C13.1, C14.1, C15.1, C16.1, C17.1, C18.1, MIC1.6 (VDD), R6.1, R13.1, R14.1, U1.1 (IOVDD), U1.10 (IOVDD), U1.22 (IOVDD), U1.33 (IOVDD), U1.42 (IOVDD), U1.44 (VREG_IN), U1.48 (USB_VDD), U1.49 (IOVDD), U2.8 (VCC), U3.2 (VOUT), U3.4 (VOUT), VR1.3 (CW)
+5V: C4.1, LEDS1.3 (5V), LEDS2.3 (5V), LEDS3.3 (5V), U3.3 (VIN), USB1.A4 (VBUS), USB1.A9 (VBUS), USB1.B4 (VBUS), USB1.B9 (VBUS)
/A: C9.1, R24.2, U7.1 (A)
/B: C10.2, R25.2, U7.2 (B)
ADC_VREF: C19.1, R13.2, R14.2, U1.43 (ADC_AVDD)
BOARD_ID_0: C1.1, C2.1, C3.1, C4.2, C6.1, C8.2, C9.2, C10.1, C11.2, C12.2, C13.2, C14.2, C15.2, C16.2, C17.2, C18.2, C19.2, C20.2, C21.2, J1.1, LEDS1.1 (GND), LEDS2.1 (GND), LEDS3.1 (GND), MIC1.1 (GND), MIC1.2 (L/R), MIC1.3 (GND), R1.1, R2.2, R12.1, SW1.3 (C), SW2.1 (A), SW2.2 (B), U1.2 (GPIO0), U1.3 (GPIO1), U1.4 (GPIO2), U1.5 (GPIO3), U1.6 (GPIO4), U1.19 (TESTEN), U1.57 (GND), U2.4 (GND), U3.1 (GND), U7.3 (C), U7.5 (2), U7.6 (MH1), U7.7 (MH2), USB1.0 (SH), USB1.1 (SH), USB1.2 (SH), USB1.3 (SH), USB1.A1 (GND), USB1.A12 (GND), USB1.B1 (GND), USB1.B12 (GND), VR1.1 (CCW), VR1.4 (MH1), VR1.5 (MH2), X1.2 (GND), X1.4 (GND)
BUTTON: SW1.1 (A), U1.34 (GPIO22)
ENC_A: R24.1, U1.35 (GPIO23)
ENC_B: R25.1, U1.36 (GPIO24)
ENC_SW: U1.37 (GPIO25), U7.4 (1)
LED_OUT_1: LEDS1.2 (DATA), U1.17 (GPIO14)
LED_OUT_2: LEDS2.2 (DATA), U1.18 (GPIO15)
LED_OUT_3: LEDS3.2 (DATA), U1.27 (GPIO16)
unnamed: LED1.1 (K), R12.2
unnamed: R7.2, SW1.2 (B)
unnamed: R6.2, SW2.4 (D), U1.26 (RUN)
unnamed: R4.2, U1.46 (USB_DM)
unnamed: R3.2, U1.47 (USB_DP)
unnamed: C11.1, C20.1, C21.1, U1.23 (DVDD), U1.45 (VREG_VOUT), U1.50 (DVDD)
unnamed: R2.1, USB1.A5 (CC1)
unnamed: R1.2, USB1.B5 (CC2)
unnamed: C1.2, R5.1, X1.3 (OSC2)
PDM_CLK: MIC1.4 (CLK), U1.32 (GPIO21)
PDM_DATA: MIC1.5 (DATA), U1.31 (GPIO20)
POT_ADC: U1.39 (GPIO27_ADC1), VR1.2 (WIPER)
QSPI_CLK: U1.52 (QSPI_SCLK), U2.6 (CLK)
QSPI_SD2: U1.54 (QSPI_SD2), U2.3 (IO2)
QSPI_SD3: U1.51 (QSPI_SD3), U2.7 (IO3)
QSPI_SP0: U1.53 (QSPI_SD0), U2.5 (DI(IO0))
QSPI_SP1: U1.55 (QSPI_SD1), U2.2 (DO(IO1))
QSPI_SS: R7.1, U1.56 (QSPI_SS), U2.1 (~CS)
STATUS_LED: LED1.2 (A), U1.13 (GPIO10)
SWCLK: J1.3, U1.24 (SWCLK)
SWDIO: J1.2, U1.25 (SWD)
USB_DM: R4.1, USB1.A7 (DN1), USB1.B7 (DN2)
USB_DP: R3.1, USB1.A6 (DP1), USB1.B6 (DP2)
XIN: C2.2, U1.20 (XIN), X1.1 (OSC1)
XOUT: R5.2, U1.21 (XOUT)

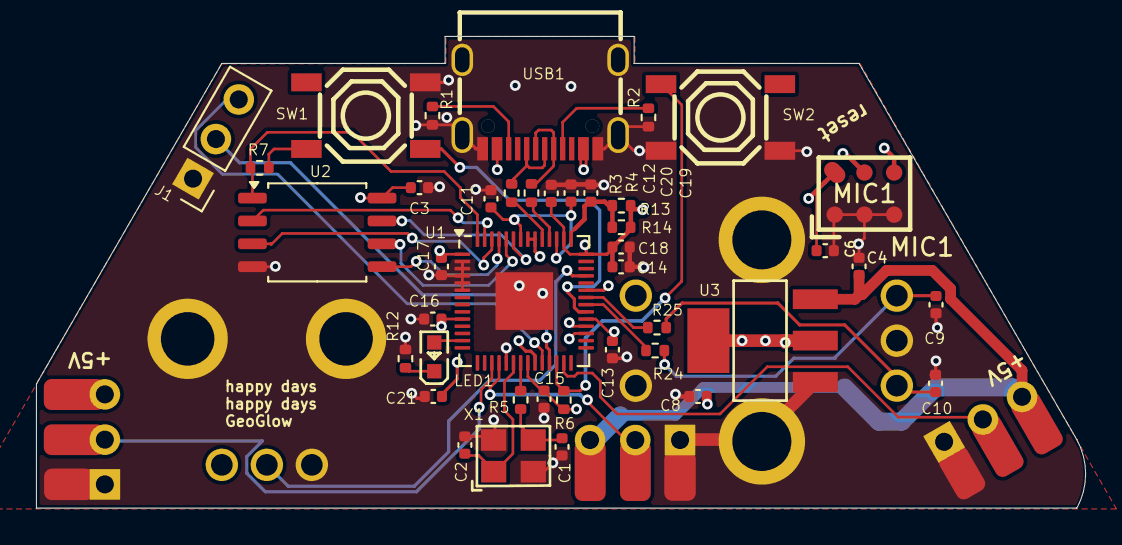
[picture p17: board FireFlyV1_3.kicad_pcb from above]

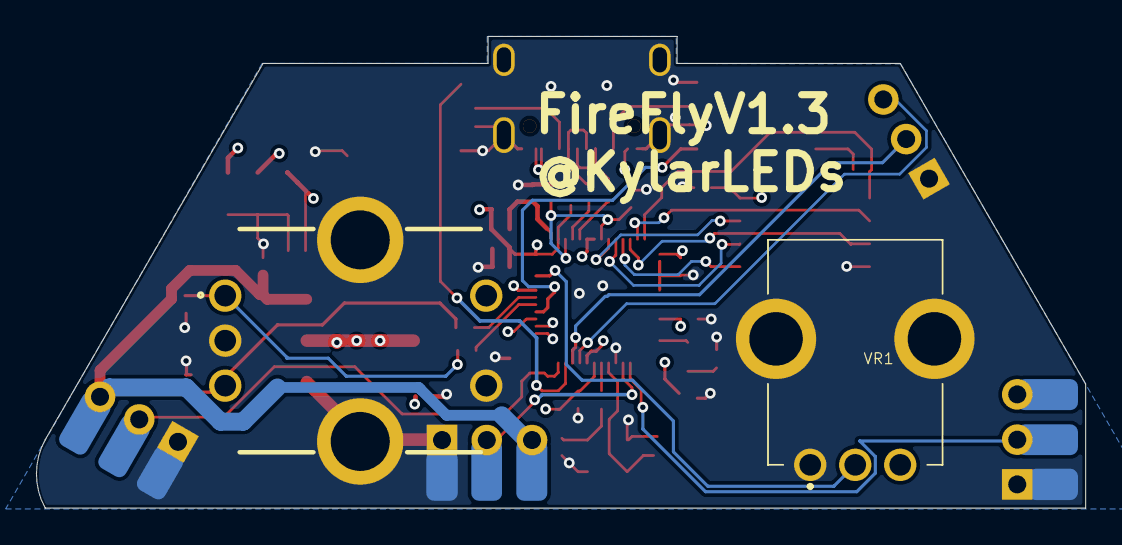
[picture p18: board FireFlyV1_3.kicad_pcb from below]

Board: 4 copper layers, 58.3 x 26.2 mm, 46 parts (4 on the bottom side), 38 nets.

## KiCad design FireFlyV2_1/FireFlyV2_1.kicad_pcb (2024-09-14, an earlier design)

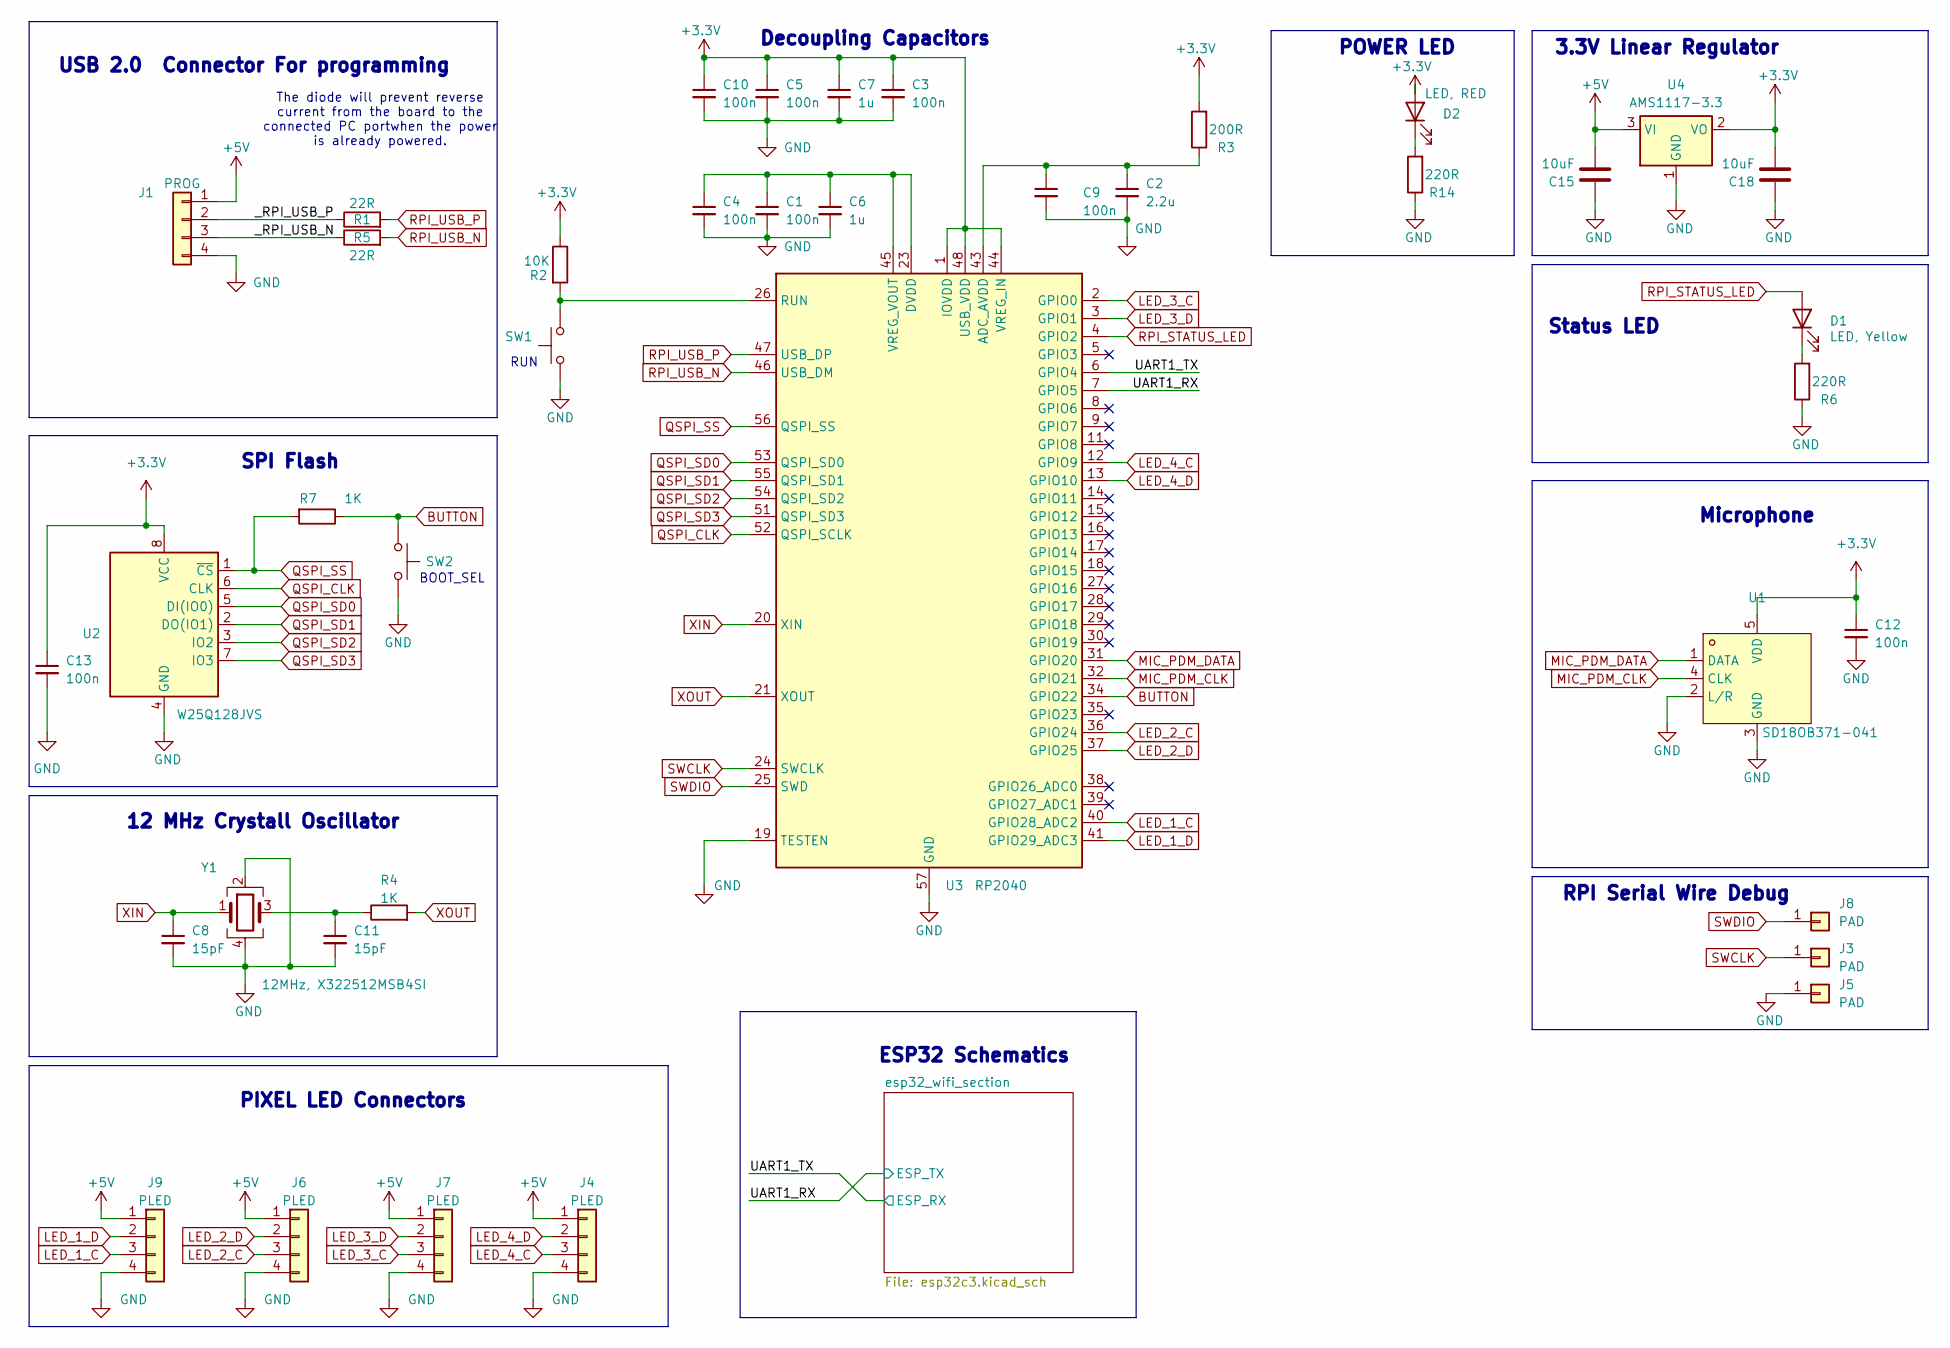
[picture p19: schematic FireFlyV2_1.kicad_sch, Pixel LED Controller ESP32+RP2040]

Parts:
C1, C3, C4, C5, C9, C10, C12, C13: 100n; C_0402_1005Metric; LCSC Part C1525
C2: 2.2u; C_0402_1005Metric; LCSC Part C12530
C6, C7: 1u; C_0402_1005Metric; LCSC Part C52923
C8, C11: 15pF; C_0402_1005Metric; LCSC Part C1548
C15, C18: 10uF; C_0603_1608Metric; LCSC Part C19702
D1: LED, Yellow; LED_0603_1608Metric; LCSC Part C72038
D2: LED, RED; LED_0603_1608Metric; LCSC Part C2286
J1: PROG; USB_PROG_PAD
J3, J5, J8: PAD; TestPoint_Pad_1.0x1.0mm
J4, J6, J7, J9: PLED; PIXEL-LED-PAD-4
R1, R5: 22R; R_0402_1005Metric; LCSC Part C25092
R2: 10K; R_0402_1005Metric; LCSC Part C25744
R3: 200R; R_0402_1005Metric; LCSC Part C25087
R4, R7: 1K; R_0402_1005Metric; LCSC Part C11702
R6, R14: 220R; R_0402_1005Metric; LCSC Part C25091
SW1, SW2: BTN; SW_SPST_B3U-1000P; LCSC Part C231329
U1: SD18OB371-041; RHLGA-5L_L3.5-W2.7-P0.82-MP23ABS1TR; LCSC Part C3040249
U2: W25Q128JVS; SOIC-8_5.275x5.275mm_P1.27mm; LCSC Part C97521
U3: RP2040; QFN-56-1EP_7x7mm_P0.4mm_EP3.2x3.2mm; LCSC Part C2040
U4: AMS1117-3.3; SOT-223-3_TabPin2; LCSC Part C6186
Y1: 12MHz, X322512MSB4SI; Crystal_SMD_3225-4Pin_3.2x2.5mm; LCSC Part C9002

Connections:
+3.3V: C3.1, C5.1, C7.1, C10.1, C12.1, C13.1, C18.1, D2.2 (A), R2.1, R3.2, U1.5 (VDD), U2.8 (VCC), U3.1 (IOVDD), U3.10 (IOVDD), U3.22 (IOVDD), U3.33 (IOVDD), U3.42 (IOVDD), U3.44 (VREG_IN), U3.48 (USB_VDD), U3.49 (IOVDD), U4.2 (VO); also elsewhere on the board
+5V: C15.1, J1.1, J4.1, J6.1, J7.1, J9.1, U4.3 (VI); also elsewhere on the board
/UART1_RX: U3.7 (GPIO5); also elsewhere on the board
/UART1_TX: U3.6 (GPIO4); also elsewhere on the board
/_RPI_USB_N: J1.3, R5.1
/_RPI_USB_P: J1.2, R1.1
BUTTON: R7.1, SW2.1, U3.34 (GPIO22)
GND: C1.2, C2.2, C3.2, C4.2, C5.2, C6.2, C7.2, C8.2, C9.2, C10.2, C11.2, C12.2, C13.2, C15.2, C18.2, J1.4, J4.4, J5.1, J6.4, J7.4, J9.4, R6.1, R14.1, SW1.2, SW2.2, U1.2 (L/R), U1.3 (GND), U2.4 (GND), U3.19 (TESTEN), U3.57 (GND), U4.1 (GND), Y1.2, Y1.4; also elsewhere on the board
LED_1_C: J9.3, U3.40 (GPIO28_ADC2)
LED_1_D: J9.2, U3.41 (GPIO29_ADC3)
LED_2_C: J6.3, U3.36 (GPIO24)
LED_2_D: J6.2, U3.37 (GPIO25)
LED_3_C: J7.3, U3.2 (GPIO0)
LED_3_D: J7.2, U3.3 (GPIO1)
LED_4_C: J4.3, U3.12 (GPIO9)
LED_4_D: J4.2, U3.13 (GPIO10)
MIC_PDM_CLK: U1.4 (CLK), U3.32 (GPIO21)
MIC_PDM_DATA: U1.1 (DATA), U3.31 (GPIO20)
unnamed: C11.1, R4.1, Y1.3
unnamed: D1.1 (K), R6.2
unnamed: D2.1 (K), R14.2
unnamed: C2.1, C9.1, R3.1, U3.43 (ADC_AVDD)
unnamed: R2.2, SW1.1, U3.26 (RUN)
unnamed: C1.1, C4.1, C6.1, U3.23 (DVDD), U3.45 (VREG_VOUT), U3.50 (DVDD)
QSPI_CLK: U2.6 (CLK), U3.52 (QSPI_SCLK)
QSPI_SD0: U2.5 (DI(IO0)), U3.53 (QSPI_SD0)
QSPI_SD1: U2.2 (DO(IO1)), U3.55 (QSPI_SD1)
QSPI_SD2: U2.3 (IO2), U3.54 (QSPI_SD2)
QSPI_SD3: U2.7 (IO3), U3.51 (QSPI_SD3)
QSPI_SS: R7.2, U2.1 (~CS), U3.56 (QSPI_SS)
RPI_STATUS_LED: D1.2 (A), U3.4 (GPIO2)
RPI_USB_N: R5.2, U3.46 (USB_DM)
RPI_USB_P: R1.2, U3.47 (USB_DP)
SWCLK: J3.1, U3.24 (SWCLK)
SWDIO: J8.1, U3.25 (SWD)
XIN: C8.1, U3.20 (XIN), Y1.1
XOUT: R4.2, U3.21 (XOUT)

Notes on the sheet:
3.3V Linear Regulator
Microphone
SPI Flash
RPI Serial Wire Debug
Decoupling Capacitors
POWER LED
12 MHz Crystall Oscillator
RUN
The diode will prevent reverse current from the board to the connected PC portwhen the power is already powered.
PIXEL LED Connectors
USB 2.0 Connector For programming
BOOT_SEL
Status LED
ESP32 Schematics

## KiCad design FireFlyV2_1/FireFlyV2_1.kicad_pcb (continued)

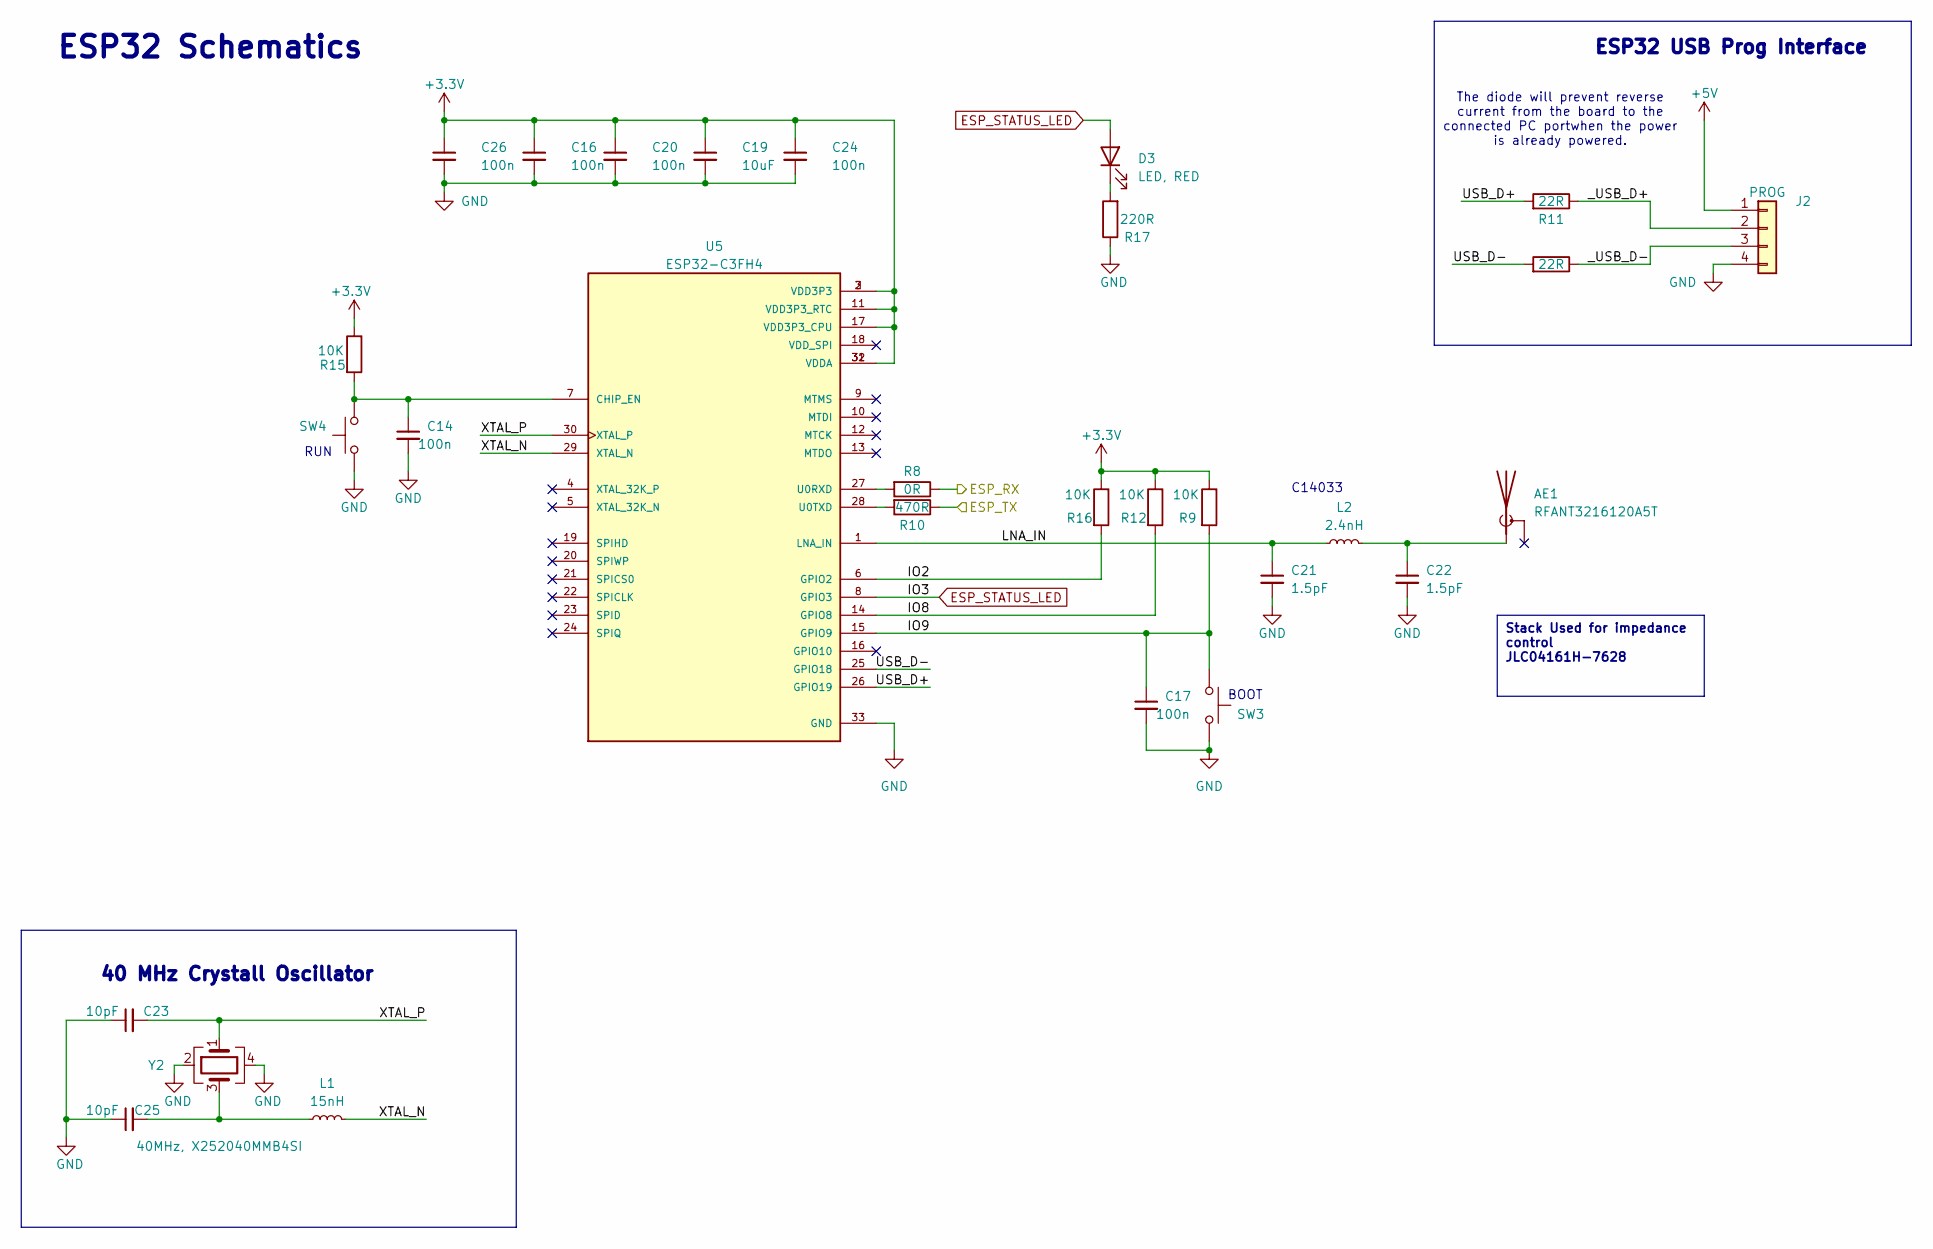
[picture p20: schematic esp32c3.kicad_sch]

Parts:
AE1: RFANT3216120A5T; FILTER-SMD_1206-2P-L3.2-W1.6-L; LCSC Part C293767
C14, C16, C17, C20, C24, C26: 100n; C_0402_1005Metric; LCSC Part C1525
C19: 10uF; C_0603_1608Metric; LCSC Part C19702
C21, C22: 1.5pF; C_0402_1005Metric; LCSC Part C1552
C23, C25: 10pF; C_0402_1005Metric; LCSC Part C32949
D3: LED, RED; LED_0603_1608Metric; LCSC Part C2286
J2: PROG; USB_PROG_PAD
L1: 15nH; L_0402_1005Metric; LCSC Part C27143
L2: 2.4nH; L_0402_1005Metric; LCSC Part C219526
R8: 0R; R_0402_1005Metric; LCSC Part C17168
R9, R12, R15, R16: 10K; R_0402_1005Metric; LCSC Part C25744
R10: 470R; R_0402_1005Metric; LCSC Part C25117
R11, R13: 22R; R_0402_1005Metric; LCSC Part C25092
R17: 220R; R_0402_1005Metric; LCSC Part C25091
SW3, SW4: BTN; SW_SPST_B3U-1000P; LCSC Part C231329
U5: ESP32-C3FH4; MPN ESP32-C3FH4; LCSC Part C2858491
Y2: 40MHz, X252040MMB4SI; Crystal_SMD_2520-4Pin_2.5x2.0mm; LCSC Part C2885592

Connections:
+3.3V: C16.1, C19.1, C20.1, C24.1, C26.1, R9.1, R12.1, R15.1, R16.1, U5.2 (VDD3P3), U5.3 (VDD3P3), U5.11 (VDD3P3_RTC), U5.17 (VDD3P3_CPU), U5.31 (VDDA), U5.32 (VDDA); also elsewhere on the board
+5V: J2.1; also elsewhere on the board
/UART1_RX: R10.1; also elsewhere on the board
/UART1_TX: R8.1; also elsewhere on the board
/esp32_wifi_section/IO2: R16.2, U5.6 (GPIO2)
/esp32_wifi_section/IO8: R12.2, U5.14 (GPIO8)
/esp32_wifi_section/IO9: C17.1, R9.2, SW3.2, U5.15 (GPIO9)
/esp32_wifi_section/LNA_IN: C21.1, L2.1, U5.1 (LNA_IN)
/esp32_wifi_section/USB_D+: R11.2, U5.26 (GPIO19)
/esp32_wifi_section/USB_D-: R13.2, U5.25 (GPIO18)
/esp32_wifi_section/XTAL_N: L1.2, U5.29 (XTAL_N)
/esp32_wifi_section/XTAL_P: C23.2, U5.30 (XTAL_P), Y2.1
/esp32_wifi_section/_USB_D+: J2.2, R11.1
/esp32_wifi_section/_USB_D-: J2.3, R13.1
ESP_STATUS_LED: D3.2 (A), U5.8 (GPIO3)
GND: C14.2, C16.2, C17.2, C19.2, C20.2, C21.2, C22.2, C23.1, C24.2, C25.1, C26.2, J2.4, R17.1, SW3.1, SW4.2, U5.33 (GND), Y2.2, Y2.4; also elsewhere on the board
unnamed: AE1.1 (A), C22.1, L2.2
unnamed: C25.2, L1.1, Y2.3
unnamed: D3.1 (K), R17.2
unnamed: C14.1, R15.2, SW4.1, U5.7 (CHIP_EN)
unnamed: R8.2, U5.27 (U0RXD)
unnamed: R10.2, U5.28 (U0TXD)

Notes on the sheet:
Stack Used for impedance control JLC04161H-7628
40 MHz Crystall Oscillator
RUN
The diode will prevent reverse current from the board to the connected PC portwhen the power is already powered.
ESP32 Schematics
C14033
ESP32 USB Prog Interface
BOOT

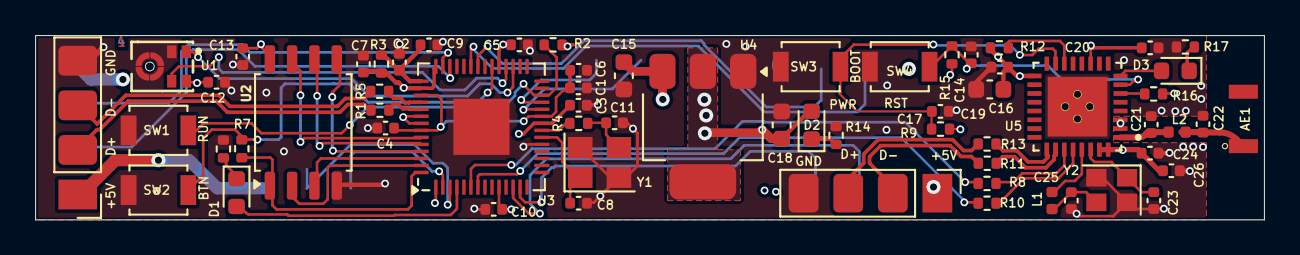
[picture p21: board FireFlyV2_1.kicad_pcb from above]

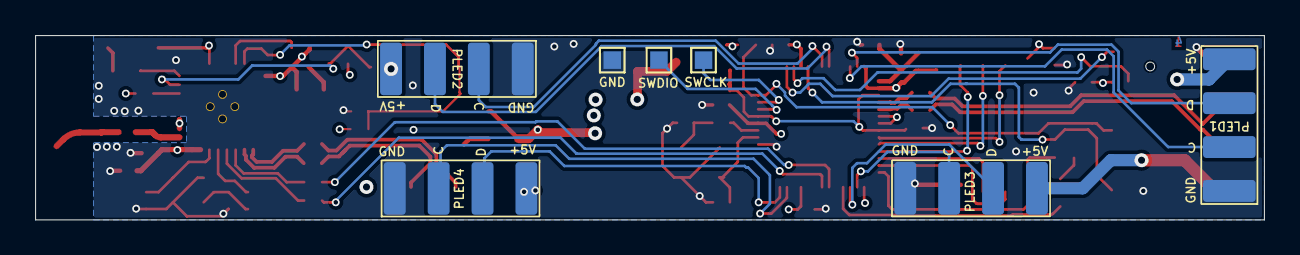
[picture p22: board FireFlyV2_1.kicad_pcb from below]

Board: 4 copper layers, 70.0 x 10.5 mm, 69 parts (7 on the bottom side), 54 nets.

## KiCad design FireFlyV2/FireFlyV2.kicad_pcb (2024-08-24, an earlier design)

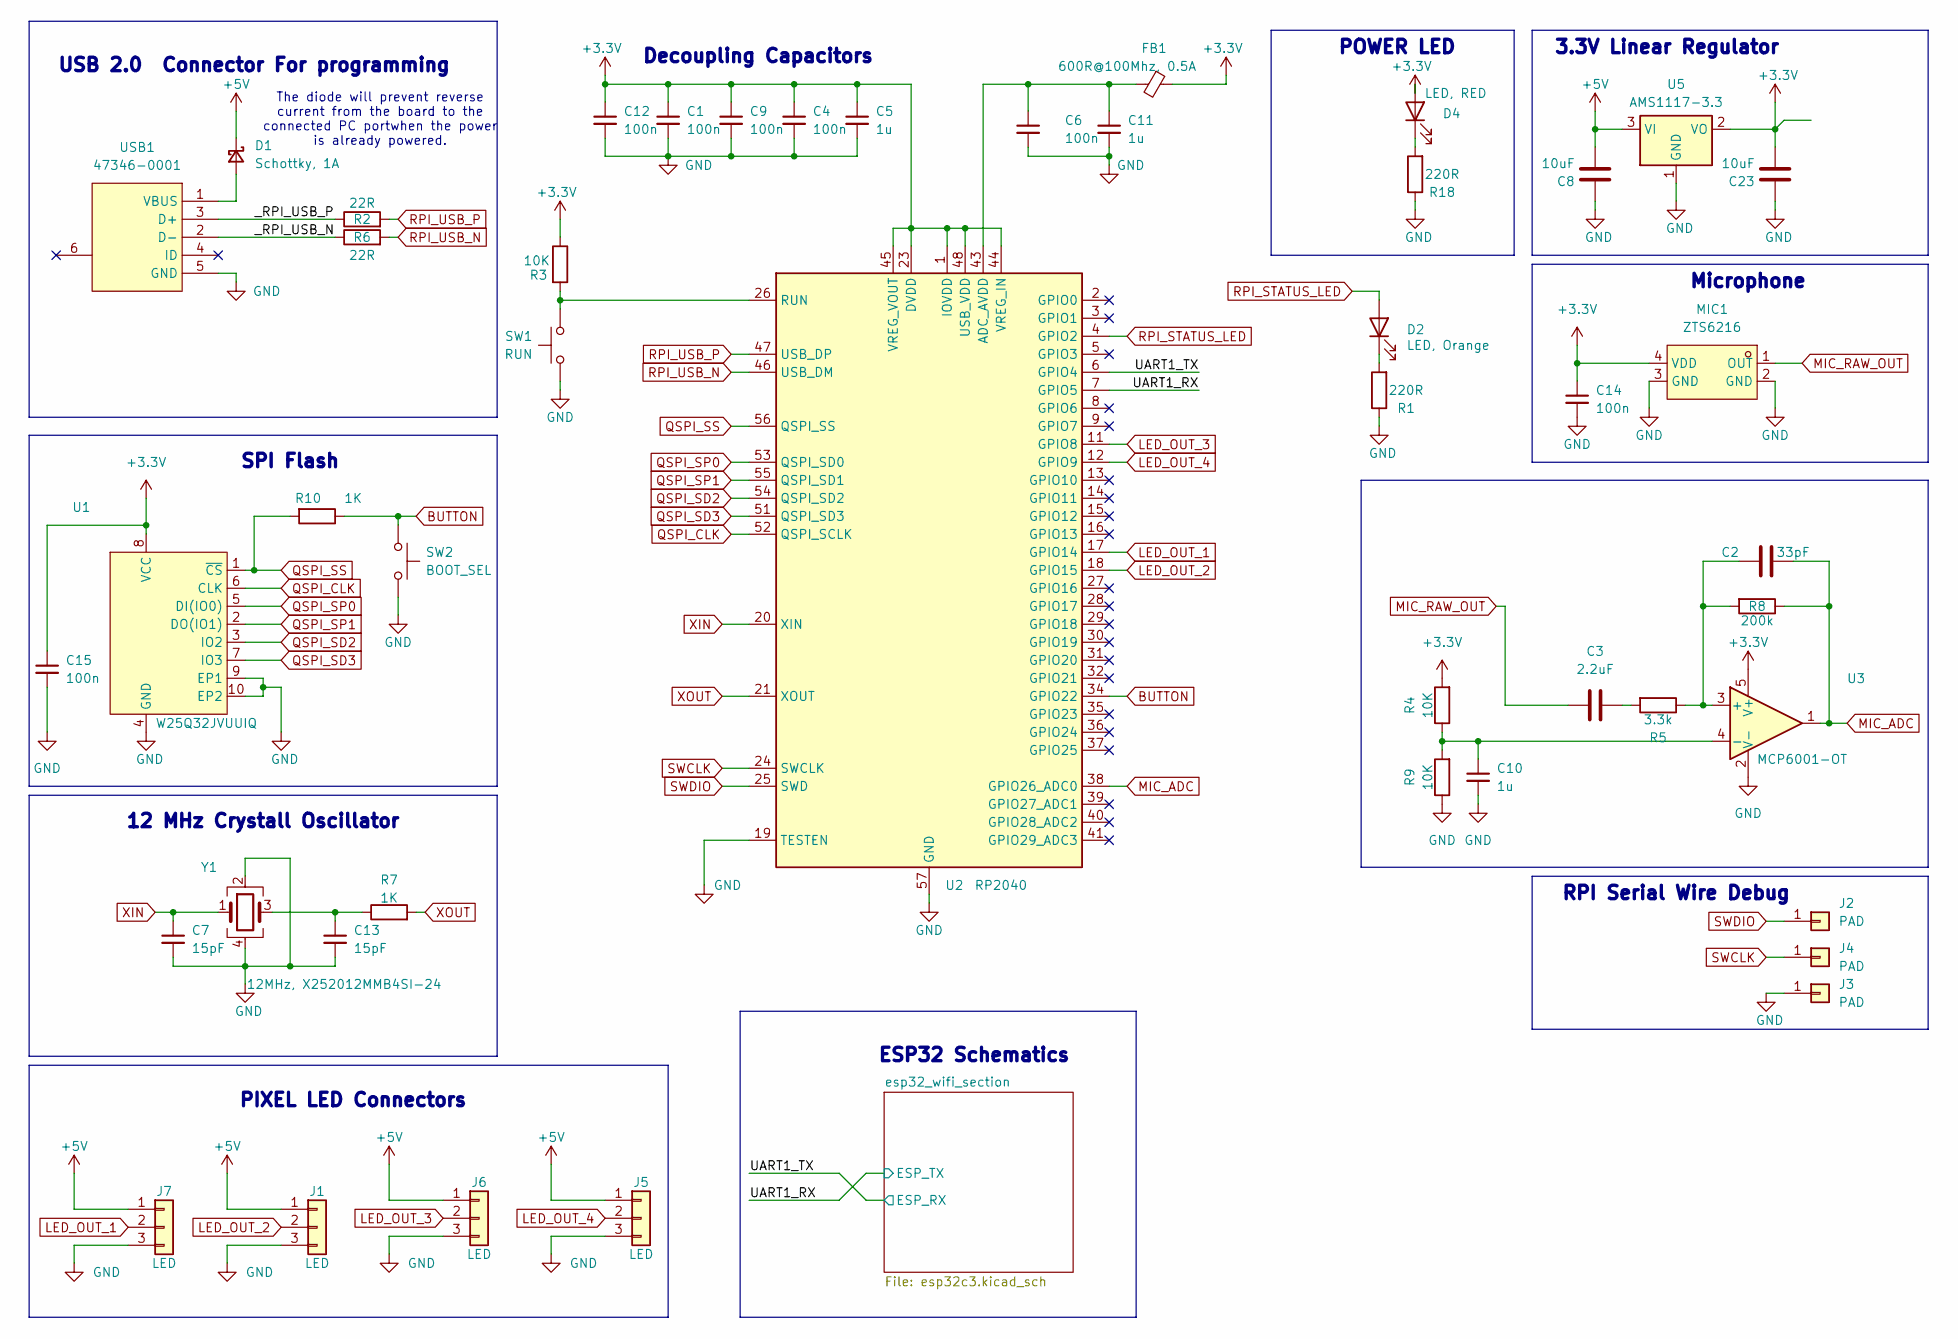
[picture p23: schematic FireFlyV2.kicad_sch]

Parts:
C1, C4, C6, C9, C12, C14, C15: 100n; C_0402_1005Metric; LCSC Part C1525
C2: 33pF; C_0402_1005Metric; LCSC Part C1562
C3: 2.2uF; C_0402_1005Metric; LCSC Part C12530
C5, C10, C11: 1u; C_0402_1005Metric; LCSC Part C52923
C7, C13: 15pF; C_0402_1005Metric; LCSC Part C1548
C8, C23: 10uF; C_0603_1608Metric; LCSC Part C385035
D1: Schottky, 1A; D_SOD-123F; LCSC Part C2900731
D2: LED, Orange; LED_0402_1005Metric; LCSC Part C273599
D4: LED, RED; LED_0402_1005Metric; LCSC Part C71911
FB1: 600R@100Mhz, 0.5A; L_0402_1005Metric; LCSC Part C96722
J1, J5, J6, J7: LED; PIXEL-LED-PAD
J2, J3, J4: PAD; TestPoint_Pad_1.0x1.0mm
MIC1: ZTS6216; MIC-SMD_4P-L2.8-W1.9-P1.84-TL; LCSC Part C481302
R1, R18: 220R; R_0402_1005Metric; LCSC Part C25091
R2, R6: 22R; R_0402_1005Metric; LCSC Part C25092
R3, R4, R9: 10K; R_0402_1005Metric; LCSC Part C25744
R5: 3.3k; R_0402_1005Metric; LCSC Part C25890
R7, R10: 1K; R_0402_1005Metric; LCSC Part C11702
R8: 200k; R_0402_1005Metric; LCSC Part C25764
SW1: RUN; SW_SPST_B3U-1000P; LCSC Part C231329
SW2: BOOT_SEL; SW_SPST_B3U-1000P; LCSC Part C231329
U1: W25Q32JVUUIQ; USON-8_L4.0-W3.0-P0.80-BL_WINBOND_UU; LCSC Part C2999380
U2: RP2040; QFN-56-1EP_7x7mm_P0.4mm_EP3.2x3.2mm; LCSC Part C2040
U3: MCP6001-OT; SOT-23-5; LCSC Part C116490
U5: AMS1117-3.3; SOT-223-3_TabPin2; LCSC Part C6186
USB1: 47346-0001; MICRO-USB-SMD_47346-0001; LCSC Part C132560
Y1: 12MHz, X252012MMB4SI-24; Crystal_SMD_2520-4Pin_2.5x2.0mm; LCSC Part C2896601

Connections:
+3.3V: C1.1, C4.1, C5.1, C9.1, C12.1, C14.1, C15.1, C23.1, D4.2 (A), FB1.1, MIC1.4 (VDD), R3.1, R4.2, U1.8 (VCC), U2.1 (IOVDD), U2.10 (IOVDD), U2.22 (IOVDD), U2.23 (DVDD), U2.33 (IOVDD), U2.42 (IOVDD), U2.44 (VREG_IN), U2.45 (VREG_VOUT), U2.48 (USB_VDD), U2.49 (IOVDD), U2.50 (DVDD), U3.5 (V+), U5.2 (VO); also elsewhere on the board
+5V: C8.1, D1.1 (K), J1.1, J5.1, J6.1, J7.1, U5.3 (VI); also elsewhere on the board
/UART1_RX: U2.7 (GPIO5); also elsewhere on the board
/UART1_TX: U2.6 (GPIO4); also elsewhere on the board
/_RPI_USB_N: R6.1, USB1.2 (D-)
/_RPI_USB_P: R2.1, USB1.3 (D+)
BUTTON: R10.1, SW2.1, U2.34 (GPIO22)
GND: C1.2, C4.2, C5.2, C6.2, C7.2, C8.2, C9.2, C10.2, C11.2, C12.2, C13.2, C14.2, C15.2, C23.2, J1.3, J3.1, J5.3, J6.3, J7.3, MIC1.2 (GND), MIC1.3 (GND), R1.1, R9.1, R18.1, SW1.2, SW2.2, U1.4 (GND), U1.9 (EP1), U1.10 (EP2), U2.19 (TESTEN), U2.57 (GND), U3.2 (V-), U5.1 (GND), USB1.5 (GND), Y1.2, Y1.4; also elsewhere on the board
LED_OUT_1: J7.2, U2.17 (GPIO14)
LED_OUT_2: J1.2, U2.18 (GPIO15)
LED_OUT_3: J6.2, U2.11 (GPIO8)
LED_OUT_4: J5.2, U2.12 (GPIO9)
MIC_ADC: C2.2, R8.1, U2.38 (GPIO26_ADC0), U3.1
MIC_RAW_OUT: C3.1, MIC1.1 (OUT)
unnamed: C3.2, R5.2
unnamed: C13.1, R7.1, Y1.3
unnamed: D1.2 (A), USB1.1 (VBUS)
unnamed: D2.1 (K), R1.2
unnamed: D4.1 (K), R18.2
unnamed: C6.1, C11.1, FB1.2, U2.43 (ADC_AVDD)
unnamed: R3.2, SW1.1, U2.26 (RUN)
unnamed: C2.1, R5.1, R8.2, U3.3 (+)
unnamed: C10.1, R4.1, R9.2, U3.4 (-)
QSPI_CLK: U1.6 (CLK), U2.52 (QSPI_SCLK)
QSPI_SD2: U1.3 (IO2), U2.54 (QSPI_SD2)
QSPI_SD3: U1.7 (IO3), U2.51 (QSPI_SD3)
QSPI_SP0: U1.5 (DI(IO0)), U2.53 (QSPI_SD0)
QSPI_SP1: U1.2 (DO(IO1)), U2.55 (QSPI_SD1)
QSPI_SS: R10.2, U1.1 (~CS), U2.56 (QSPI_SS)
RPI_STATUS_LED: D2.2 (A), U2.4 (GPIO2)
RPI_USB_N: R6.2, U2.46 (USB_DM)
RPI_USB_P: R2.2, U2.47 (USB_DP)
SWCLK: J4.1, U2.24 (SWCLK)
SWDIO: J2.1, U2.25 (SWD)
XIN: C7.1, U2.20 (XIN), Y1.1
XOUT: R7.2, U2.21 (XOUT)

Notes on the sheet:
3.3V Linear Regulator
Microphone
SPI Flash
RPI Serial Wire Debug
Decoupling Capacitors
POWER LED
12 MHz Crystall Oscillator
The diode will prevent reverse current from the board to the connected PC portwhen the power is already powered.
PIXEL LED Connectors
USB 2.0 Connector For programming
ESP32 Schematics


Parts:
AE1: RFANT3216120A5T; FILTER-SMD_1206-2P-L3.2-W1.6-L; LCSC Part C127629
C16, C18, C21, C22, C25: 100n; C_0402_1005Metric; LCSC Part C1525
C17: 10u; C_0603_1608Metric; LCSC Part C385035
C19, C24: 10pF; C_0402_1005Metric; LCSC Part C696913
C20, C26: 1.5pF; C_0402_1005Metric; LCSC Part C76900
D3: LED, BLUE; LED_0402_1005Metric; LCSC Part C7496802
D5: Schottky, 1A; D_SOD-123F; LCSC Part C2900731
L1: 2.7nH; L_0402_1005Metric; LCSC Part C98058
L2: 24nH; L_0402_1005Metric; LCSC Part C341784
L3: 6.8nH; L_0402_1005Metric; LCSC Part C77110
R11, R12, R14: 10K; R_0402_1005Metric; LCSC Part C25744
R13: 220R; R_0402_1005Metric; LCSC Part C25091
R15, R17: 22R; R_0402_1005Metric; LCSC Part C25092
R16: 500R; R_0402_1005Metric; LCSC Part C77110
SW3: BOOT; SW_SPST_B3U-1000P; LCSC Part C231329
SW4: RUN; SW_SPST_B3U-1000P; LCSC Part C231329
U4: ESP32-C3FH4; MPN ESP32-C3FH4; LCSC Part C2858491
USB2: 47346-0001; MICRO-USB-SMD_47346-0001; LCSC Part C132560
Y2: 40MHz, X252040MMB4SI; Crystal_SMD_2520-4Pin_2.5x2.0mm; LCSC Part C2885592

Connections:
+3.3V: C16.1, C17.1, C18.1, C21.1, C25.1, R11.1, R12.1, R14.1, U4.2 (VDD3P3), U4.3 (VDD3P3), U4.11 (VDD3P3_RTC), U4.17 (VDD3P3_CPU), U4.18 (VDD_SPI), U4.31 (VDDA), U4.32 (VDDA); also elsewhere on the board
+5V: D5.1 (K); also elsewhere on the board
/UART1_RX: R16.1; also elsewhere on the board
/UART1_TX: U4.27 (U0RXD); also elsewhere on the board
/esp32_wifi_section/IO2: R12.2, U4.6 (GPIO2)
/esp32_wifi_section/IO8: R11.2, U4.14 (GPIO8)
/esp32_wifi_section/IO9: SW3.2, U4.15 (GPIO9)
/esp32_wifi_section/IO10: U4.16 (GPIO10)
/esp32_wifi_section/LNA_IN: C20.1, L1.1, U4.1 (LNA_IN)
/esp32_wifi_section/USB_D+: R17.2, U4.25 (GPIO18)
/esp32_wifi_section/USB_D-: R15.2, U4.26 (GPIO19)
/esp32_wifi_section/XTAL_N: L2.2, U4.29 (XTAL_N)
/esp32_wifi_section/XTAL_P: C24.2, U4.30 (XTAL_P), Y2.1
/esp32_wifi_section/_USB_D+: R17.1, USB2.2 (D-)
/esp32_wifi_section/_USB_D-: R15.1, USB2.3 (D+)
ESP_STATUS_LED: D3.2 (A), U4.8 (GPIO3)
GND: C16.2, C17.2, C18.2, C19.1, C20.2, C21.2, C22.2, C24.1, C25.2, C26.2, R13.1, SW3.1, SW4.2, U4.33 (GND), USB2.5 (GND), Y2.2, Y2.4; also elsewhere on the board
unnamed: AE1.1 (A), L3.2
unnamed: C19.2, L2.1, Y2.3
unnamed: C26.1, L1.2, L3.1
unnamed: D3.1 (K), R13.2
unnamed: D5.2 (A), USB2.1 (VBUS)
unnamed: C22.1, R14.2, SW4.1, U4.7 (CHIP_EN)
unnamed: R16.2, U4.28 (U0TXD)

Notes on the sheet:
Stack Used for impedance control JLC04161H-7628
40 MHz Crystall Oscillator
The diode will prevent reverse current from the board to the connected PC portwhen the power is already powered.
ESP32 Schematics
ESP32 USB Prog Interface



Board: 4 copper layers, 67.7 x 10.5 mm, 75 parts (7 on the bottom side), 54 nets.

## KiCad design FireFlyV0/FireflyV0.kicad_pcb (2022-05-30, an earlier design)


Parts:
C1, C2, C3: C0805C104M5RAC; CAPC2012X88N; Mouser Part Number 80-C0805C104M5RAC
J1, J2, J3: USB4125-GF-A-0190; USB4125GFA0190_nosilk; Mouser Part Number 640-USB4125-GF-A-190
J4: Conn_01x04; PinHeader_1x04_P2.54mm_Vertical
J5: Conn_01x03; PinHeader_1x03_P2.54mm_Vertical
LEDS1, LEDS3: ledstrip_3pin_5mm
LEDS2, LEDS4: ledstrip_3pin_10mm
MK1: CMM-4737DT-26186-TR; CMM4737DT26186TR; Mouser Part Number 490-CMM4737DT26186TR
R1, R2: RC0805JR-071M6L; RESC2012X60N; Mouser Part Number 603-RC0805JR-071M6L
U1: PEC12R-4215F-S0024; PEC12R-4XXXF-SXXXX_court; Mouser Part Number 652-PEC12R-4215F-S24
U2: Pico; RPi_Pico_SMD_TH_removes2
VR1: PTV09A-4020F-B104; PTV09A4020FB103; Mouser Part Number 652-PTV09A-4020FB104

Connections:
3V3: C3.1, MK1.6 (VDD), U2.36 (3V3), VR1.3 (CW)
5V: J1.A9 (VBUS_1), J1.B9 (VBUS_2), J2.A9 (VBUS_1), J2.B9 (VBUS_2), J3.A9 (VBUS_1), J3.B9 (VBUS_2), J4.2, J5.3, LEDS1.3 (5V), LEDS2.3 (5V), LEDS3.3 (5V), LEDS4.3 (5V), U2.40 (VBUS)
/A: C1.2, R1.2, U1.1 (A)
/B: C2.1, R2.2, U1.2 (B)
APA_1: J4.1, U2.20 (GPIO15)
ENC_A: R1.1, U2.29 (GPIO22)
ENC_B: R2.1, U2.31 (GPIO26_ADC0)
ENC_SW: U1.4 (1), U2.34 (GPIO28_ADC2)
GND: C1.1, C2.2, C3.2, J1.A12 (GND_1), J1.B12 (GND_2), J1.MH1, J1.MH2, J1.MH3, J1.MH4, J2.A12 (GND_1), J2.B12 (GND_2), J2.MH1, J2.MH2, J2.MH3, J2.MH4, J3.A12 (GND_1), J3.B12 (GND_2), J3.MH1, J3.MH2, J3.MH3, J3.MH4, J4.4, J5.1, LEDS1.1 (GND), LEDS2.1 (GND), LEDS3.1 (GND), LEDS4.1 (GND), MK1.1 (GND_1), MK1.2 (L/R), MK1.3 (GND_2), U1.3 (C), U1.5 (2), U1.6 (MH1), U1.7 (MH2), U2.23 (GND), U2.28 (GND), U2.33 (AGND), U2.38 (GND), VR1.1 (CCW), VR1.4 (MH1), VR1.5 (MH2)
LED_DATA_1: J4.3, LEDS1.2 (DATA), LEDS4.2 (DATA), U2.21 (GPIO16); also elsewhere on the board
LED_DATA_2: J5.2, LEDS2.2 (DATA), LEDS3.2 (DATA), U2.22 (GPIO17); also elsewhere on the board
PDM_CLK: MK1.4 (CLOCK), U2.27 (GPIO21)
PDM_DATA: MK1.5 (DATA), U2.26 (GPIO20)
POT_ADC: U2.32 (GPIO27_ADC1), VR1.2 (WIPER)

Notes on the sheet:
Main Components: [X]Pico [X]Pot [X]Encoder [X]LED port [X]USBC [X]PDM mic Secondary Components: [ ]Analog Filter [ ]Capacitors [ ]Resistors [ ]Bypass Capacitor [ ]LED Resistor Pico Pin Usage: [ ]USBC - GND [ ]USBC - 5V [ ]PDM - CLK [ ]PDM - DATA [ ]PDM - 3.3V [ ]POT - ADC [ ]POT - GND [ ]POT - 3.3V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



Board: 2 copper layers, 63.2 x 43.1 mm, 20 parts (2 on the bottom side), 14 nets.

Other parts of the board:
R**: RESC2012X60N
R**#2: RESC2012X60N

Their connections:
LED_DATA_1: R**#2.1, R**#2.2; also elsewhere on the board
LED_DATA_2: R**.1, R**.2; also elsewhere on the board

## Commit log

2022-05-30 Initial rev 0
    [FireflyV0.kicad_pcb, FireflyV0.kicad_sch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]
2024-08-10 Beginning FireFlyV1
    [FireFlyV1.kicad_pcb, FireFlyV1.kicad_sch, FireflyV0.kicad_pcb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]
2024-08-10 finished first draft of schematic
    [FireFlyV1.kicad_sch]
2024-08-11 lower cost regulator and crystal
    [FireFlyV1.kicad_sch]
2024-08-11 FireFlyV1 power pins
    [FireFlyV1.kicad_sch]
2024-08-11 FireFlyV1 PCB begin
    [FireFlyV1.kicad_pcb, FireFlyV1.kicad_sch, pyvenv.cfg]
2024-08-11 FireFlyV1 components layout initial thoughts
    [FireFlyV1.kicad_pcb, FireFlyV1.kicad_sch]
2024-08-12 FireFlyV1 mostly fit on the board
    [FireFlyV1.kicad_pcb, FireFlyV1.kicad_sch]
2024-08-12 FireFlyV1 everything on board
    [FireFlyV1.kicad_pcb, FireFlyV1.kicad_sch]
2024-08-12 Questionable routing decisions
    [FireFlyV1.kicad_pcb, FireFlyV1.kicad_sch]
2024-08-12 Allowed the autorouter to try
    [FireFlyV1.kicad_pcb]
2024-08-12 removed unused backup file
    [FireFlyV1.kicad_pcb]
2024-08-12 Include LED Footprints
2024-08-13 First JLCPCB Order
    [FireFlyV1.kicad_pcb]
2024-08-18 Add BOM and schematic pdfFireFlyV1
    [FireFlyV1_bom.csv, FireFlyV1_designators.csv, FireFlyV1_positions.csv]
2024-08-24 Add FireFlyV1_1 and FireFlyV2 as ordered
    [ESP32-C3FH4.step, FireFlyV1_1.kicad_pcb, FireFlyV1_1.kicad_sch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]
2024-09-14 Adding firefly v1.2 and v2.1 as ordered
    [ESP32-C3FH4.step, FIireFlyV2_1.csv, FireFlyV1_1_bom.csv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]
2024-09-30 Adding FireflyV2.2 as orderable
    [ESP32-C3FH4.step, FireFlyV2_2.kicad_pcb, FireFlyV2_2.kicad_sch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]
2024-12-14 FireFlyV3 dev board ordered
    [ESP32-C3FH4.step, FireFlyV3_0.csv, FireFlyV3_0.kicad_pcb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]
2025-08-15 Added V1_3 and V3_1.
    [FireFlyV1_3.kicad_pcb, FireFlyV1_3.kicad_sch, FireFlyV1_3_bom.csv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]
